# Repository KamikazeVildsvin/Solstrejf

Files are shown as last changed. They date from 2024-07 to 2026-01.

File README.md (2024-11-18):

# Solstrejf - 4 Voice Sine Wave Drone Oscillator
This repository contains the simulation, schematic ,and PCB files for **Solstrejf**.
Some custom KiCad footprints, 3D models, and symbols are used in this project. 
This is included as a git submodule, which means that if you want to work with the KiCad projects in this repo, it should be cloned with the `--recursive` option like so: 

```
git clone --recursive "https://github.com/KamikazeVildsvin/Solstrejf.git"
```

### Introduction & Overview
Solstrejf, roughly translated from Danish to "sun streak" or "sun touch", is a four-voice analog sine wave drone oscillator. 
I was on a hike in Sweden out near a beautiful forest lake just around the break of dawn. 
The way the sun interacted with nature gave me a real sense of calm and ease. 
At that moment I thought, what if I could create an instrument that would be able to replicate this feeling? 
A sine wave drone synthesizer came to my mind, similar to the early Musique Concrète test equipment techniques.

###### Block Diagram
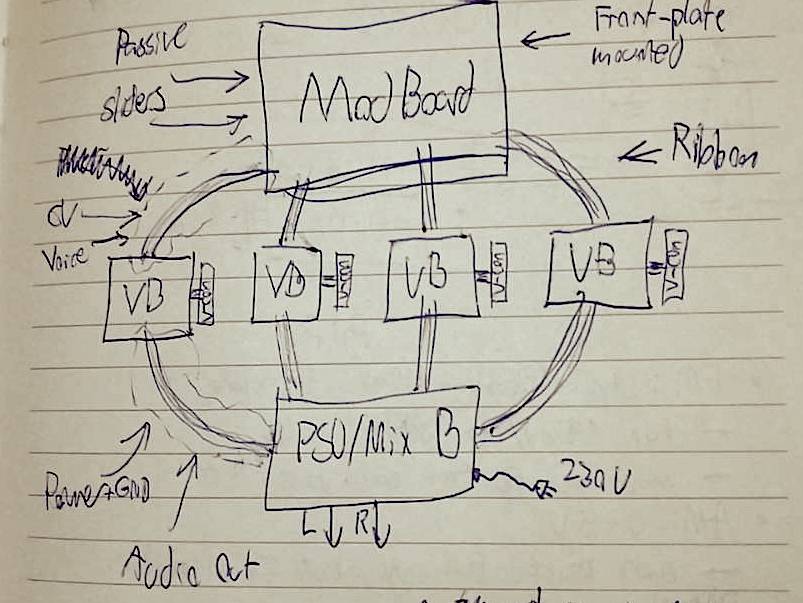
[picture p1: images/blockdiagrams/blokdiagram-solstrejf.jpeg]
Solstrejf Block Diagram


I wanted the instrument to be playful and interactive. 
Four sine wave oscillators in itself are maybe not that interesting and can become static. 
A modulation matrix, which would allow for all four voices to modulate parameters like frequency and amplitude on all other voices would create more complex soundscapes. 
The basic idea and block diagram can be seen above, where four identical voice boards are connected to the mod-matrix board and a power supply/mixer board for output summation.

###### Modulation Matrix & Voice Control Interface
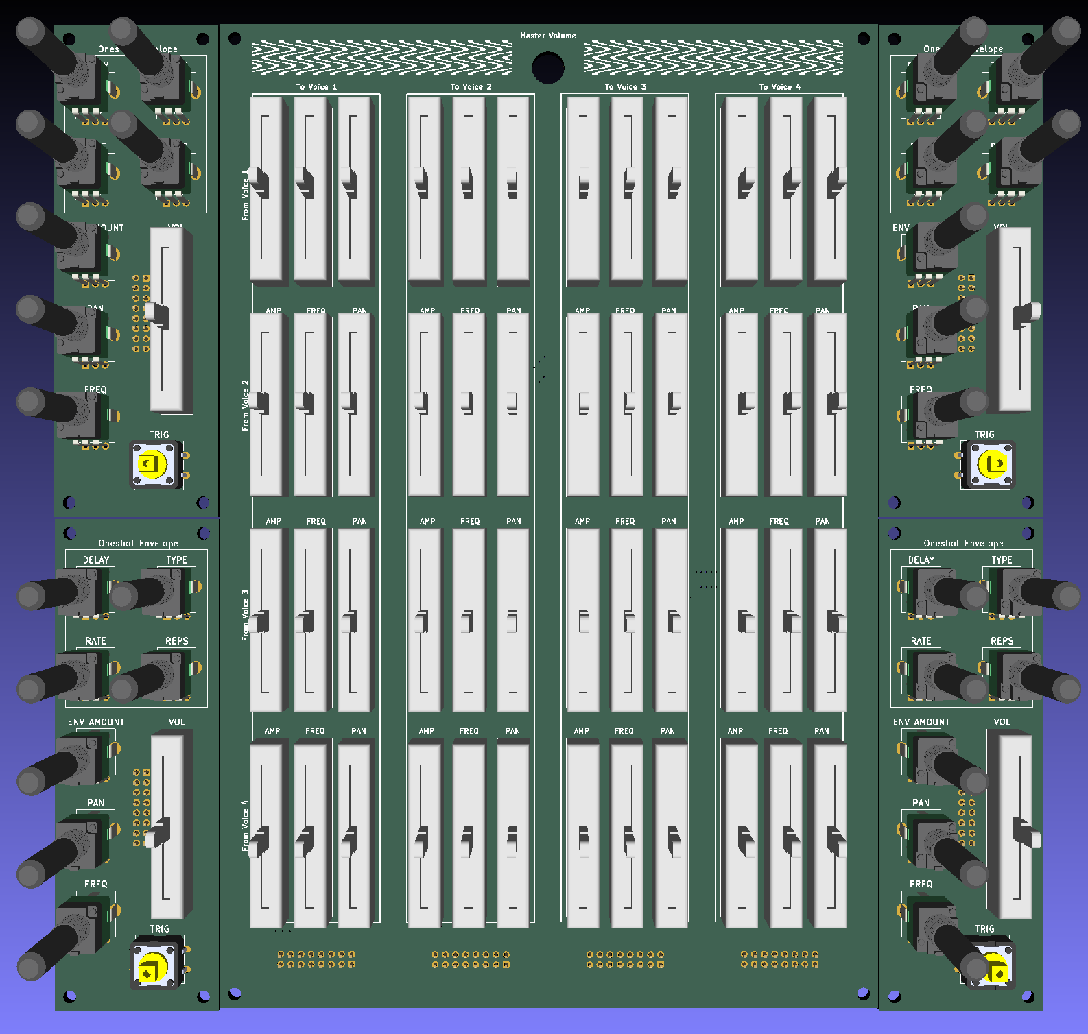
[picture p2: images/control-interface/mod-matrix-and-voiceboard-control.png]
Control Interface


The image above is a render of the modulation matrix and four of the voice board control front panels.
This is essentially user interface of the synthesizer.

## PCB's - KiCad Projects
As indicated by the block diagram above, Solstrejf is broken into four different sub-blocks and PCB's:

- A Power Supply Unit (PSU) & Mixer PCB
- A Modulation Matrix PCB
- A Voice board PCB (x4)
- A Voice board Front Panel PCB (x4)

Each of these PCB's have their own KiCad project with an associated schematic. 
The [`schematics`](schematics) directory contains some of the latest prints of the different schematics. 
The revision may not match with the KiCad files, so be sure to double check the actual KiCad project files to be certain.

#### Interactive BOM
All of the four PCB's have an interactive BOM which is generated using the [InteractiveHtmlBom](https://github.com/openscopeproject/InteractiveHtmlBom) KiCad plugin.
The interactive bom allows to see where the components should be placed on the board and also have a checklist build in, which makes it much easier to assemble the PCB's.
You can also export the BOM to a CSV or TXT file for a more traditional BOM.

### PSU / Audio Mixer
Use to generate the +/-15V supply and sum all of the left and right audio channels of the four voices.

[KiCad Project Files](pcb/solstrejf-PSU-mixer/)

[Link to interactive BOM](https://html-preview.github.io/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)

###### PCB
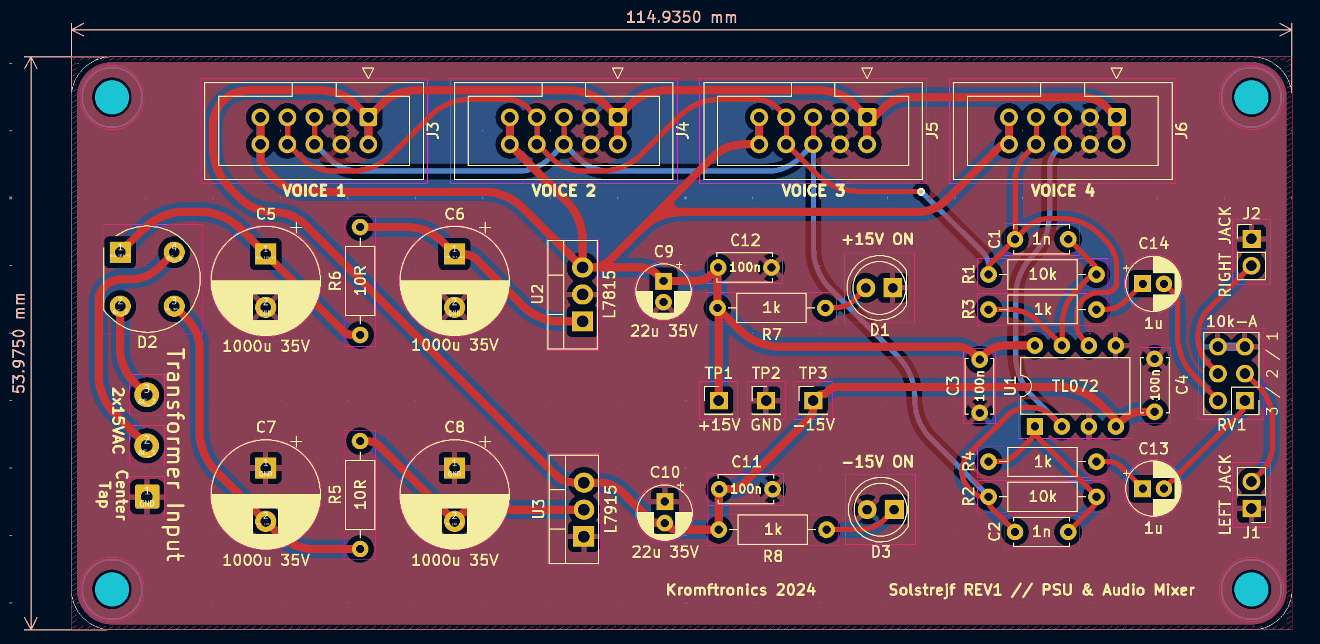
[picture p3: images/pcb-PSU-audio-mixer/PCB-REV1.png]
PSU/audio-mixer PCB


###### 3D Model : Top View
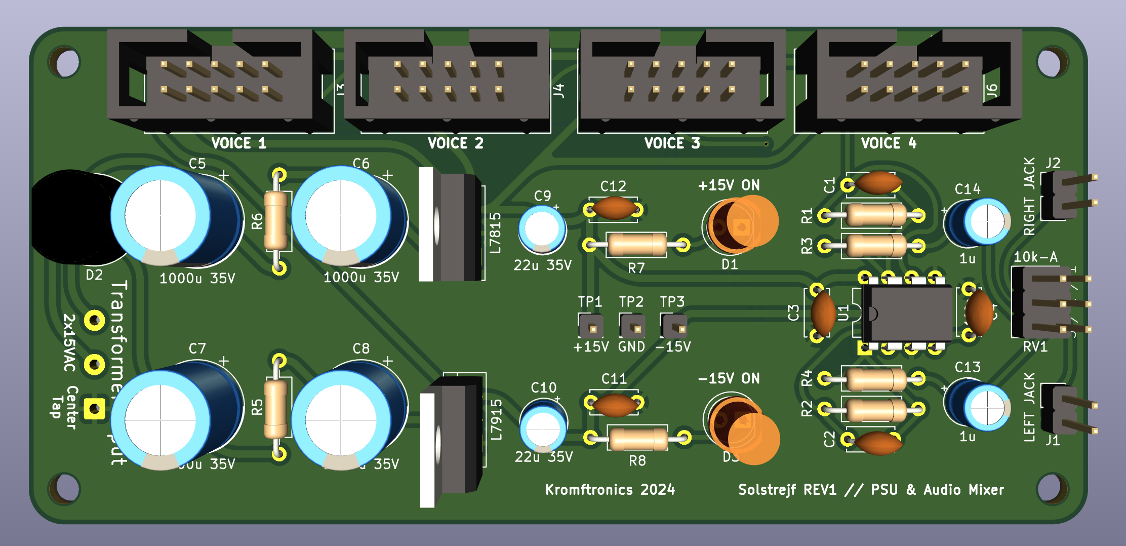
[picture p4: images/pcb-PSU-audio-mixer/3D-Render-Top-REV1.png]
PSU/audio-mixer Top


###### 3D Model : Side View
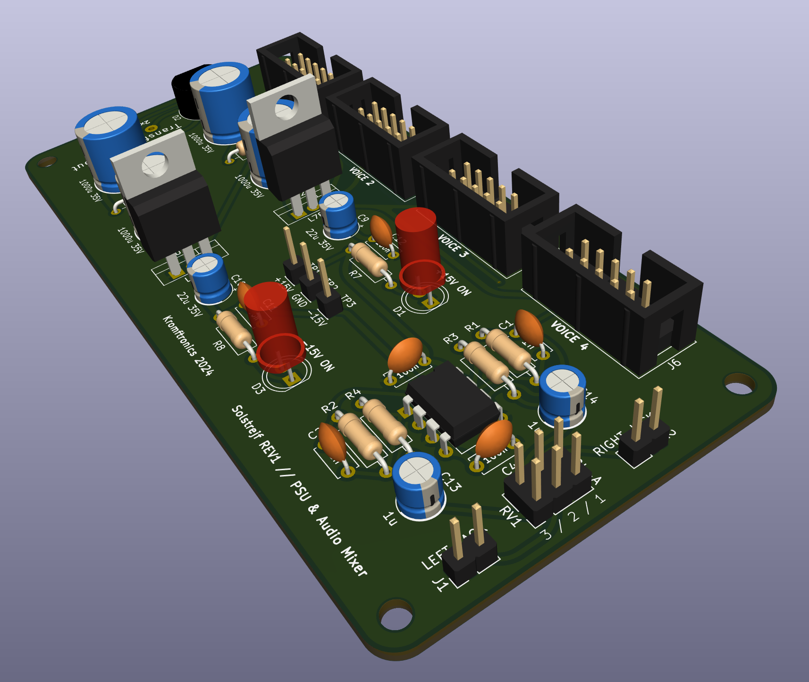
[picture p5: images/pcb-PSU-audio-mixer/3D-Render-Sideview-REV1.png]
PSU/audio-mixer Side


### Mod-Matrix
Connects to each of the four voice boards to route the modulation from and to each of the voices.
Each voice can modulate the amplitude, frequency and pan of all other voices.

[KiCad Project Files](pcb/solstrejf-modmatrix-pots)

[Link to interactive BOM](https://html-preview.github.io/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)

###### PCB 
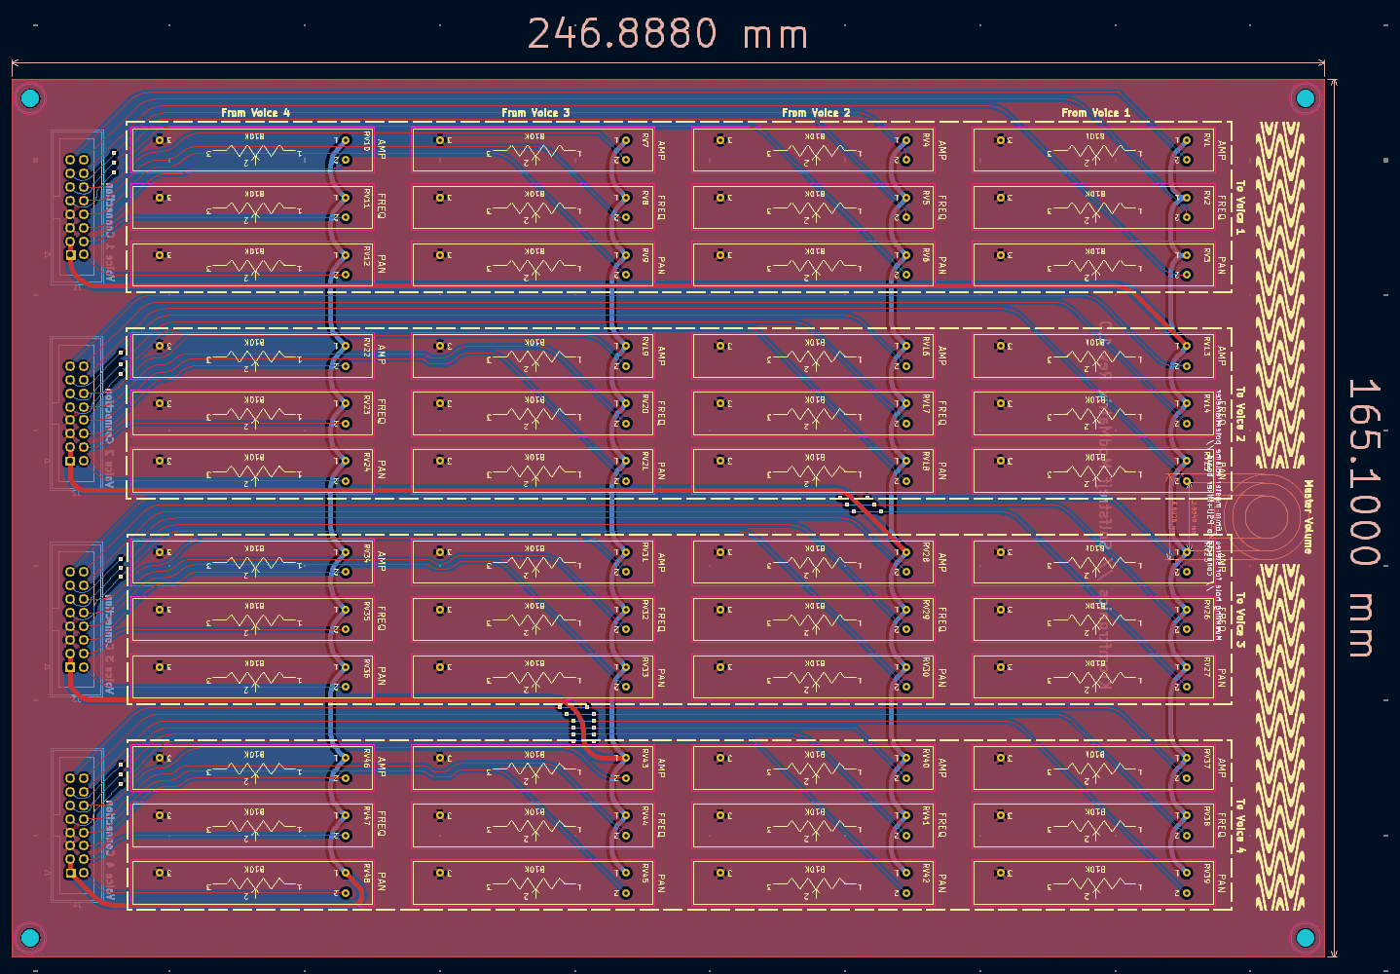
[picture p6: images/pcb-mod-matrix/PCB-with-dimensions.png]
Mod-Matrix PCB


###### 3D Model : Front-Side
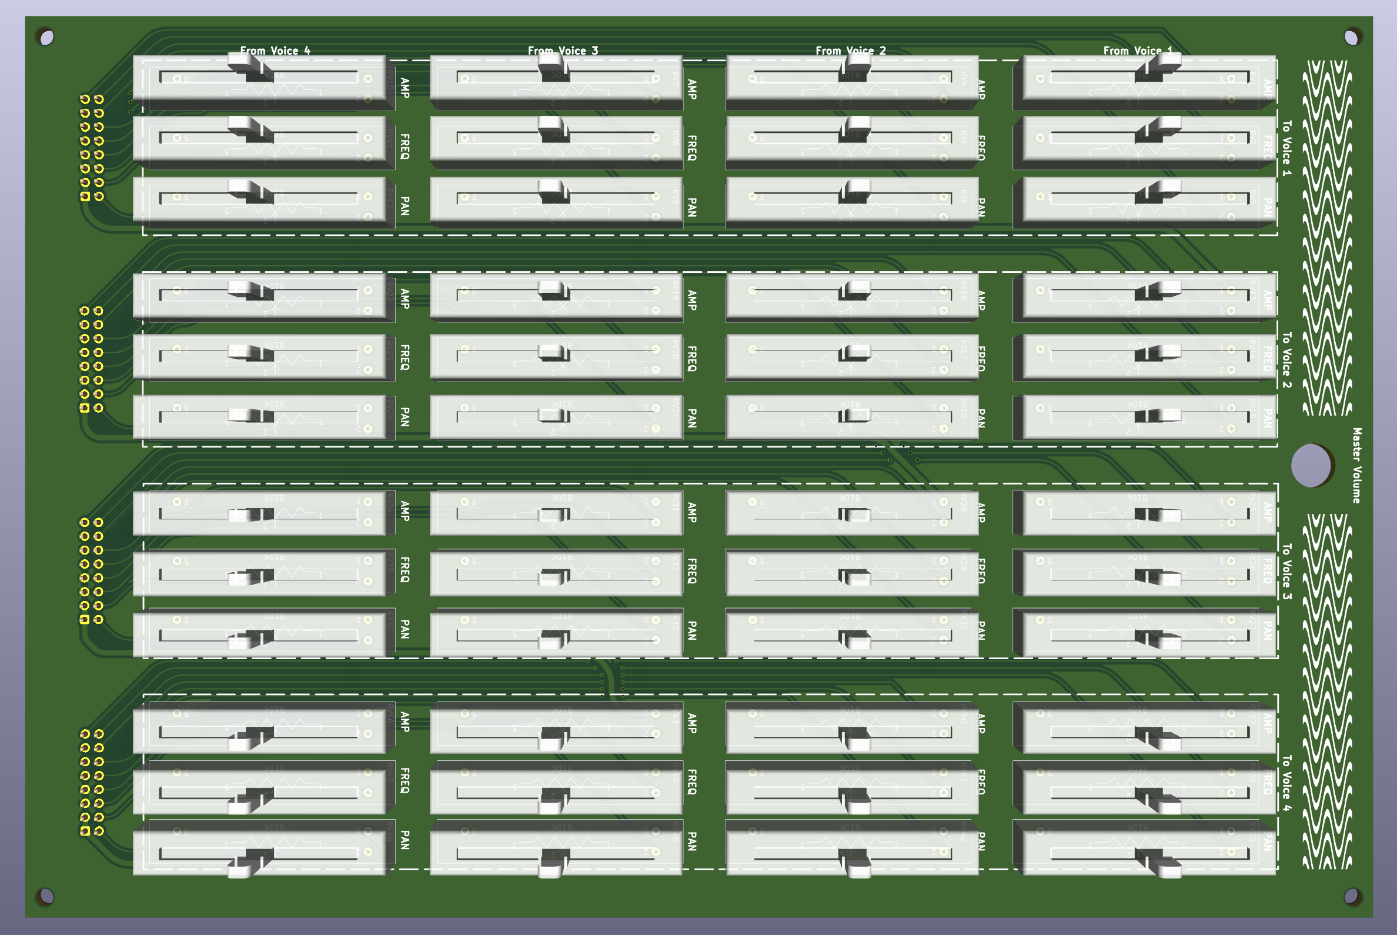
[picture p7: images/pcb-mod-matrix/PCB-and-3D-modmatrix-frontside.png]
Mod-Matrix PCB Front


###### 3D Model : Back-Side 
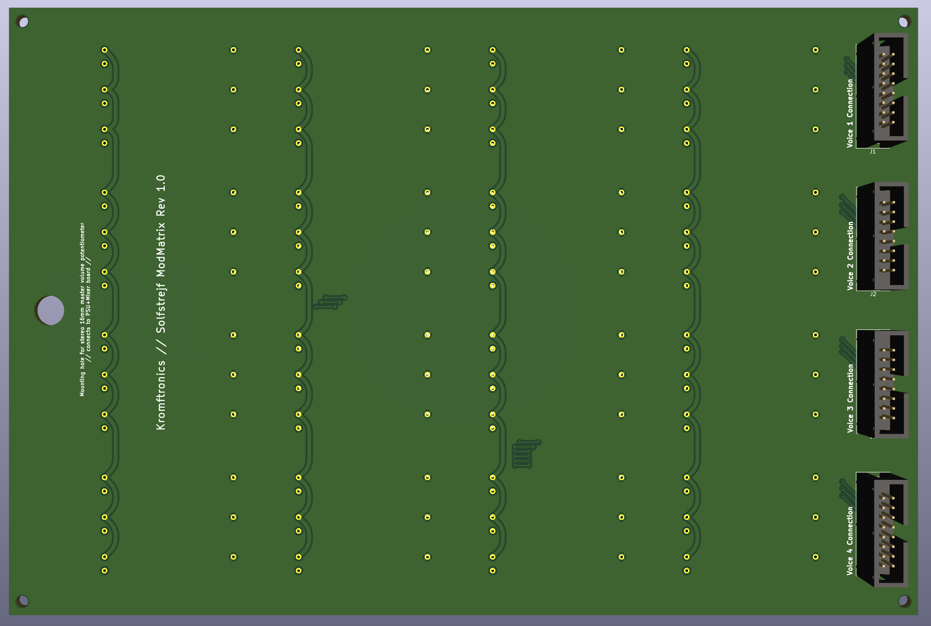
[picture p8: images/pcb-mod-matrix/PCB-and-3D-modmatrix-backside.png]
Mod-Matrix PCB Back


### Voice board 
The voice board is the actual sine wave oscillator and control voltage board.
Solstrejf consists of four of these voice boards.

[KiCad Project Files](pcb/solstrejf-voiceboard-core/)

[Link to interactive BOM](https://html-preview.github.io/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)

###### PCB
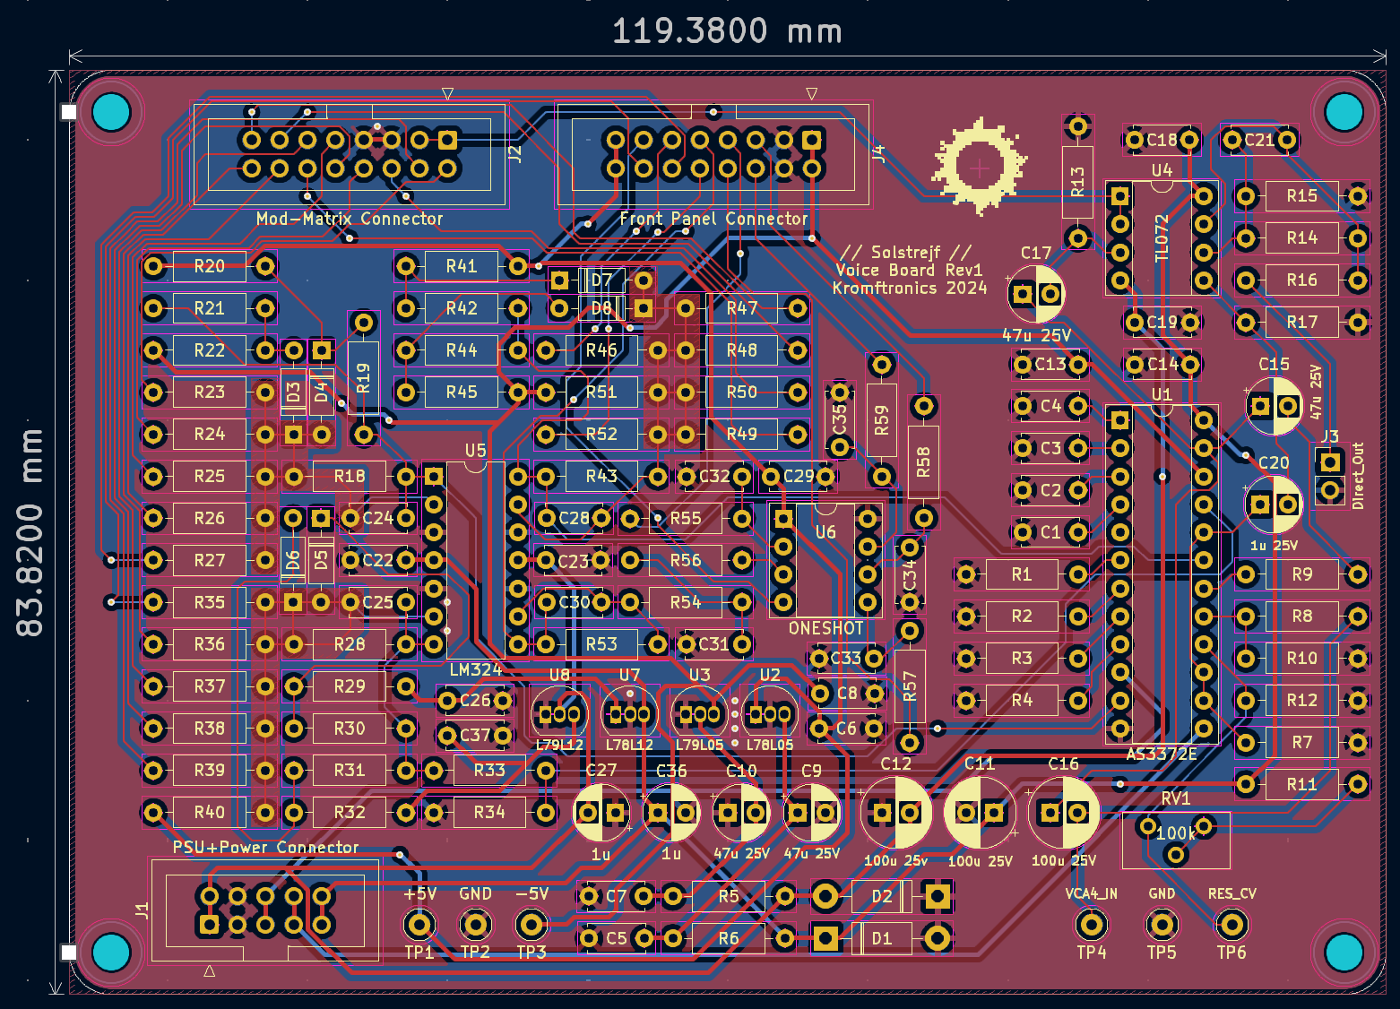
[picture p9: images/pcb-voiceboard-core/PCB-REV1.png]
Voice Board PCB


###### 3D Model : Top View
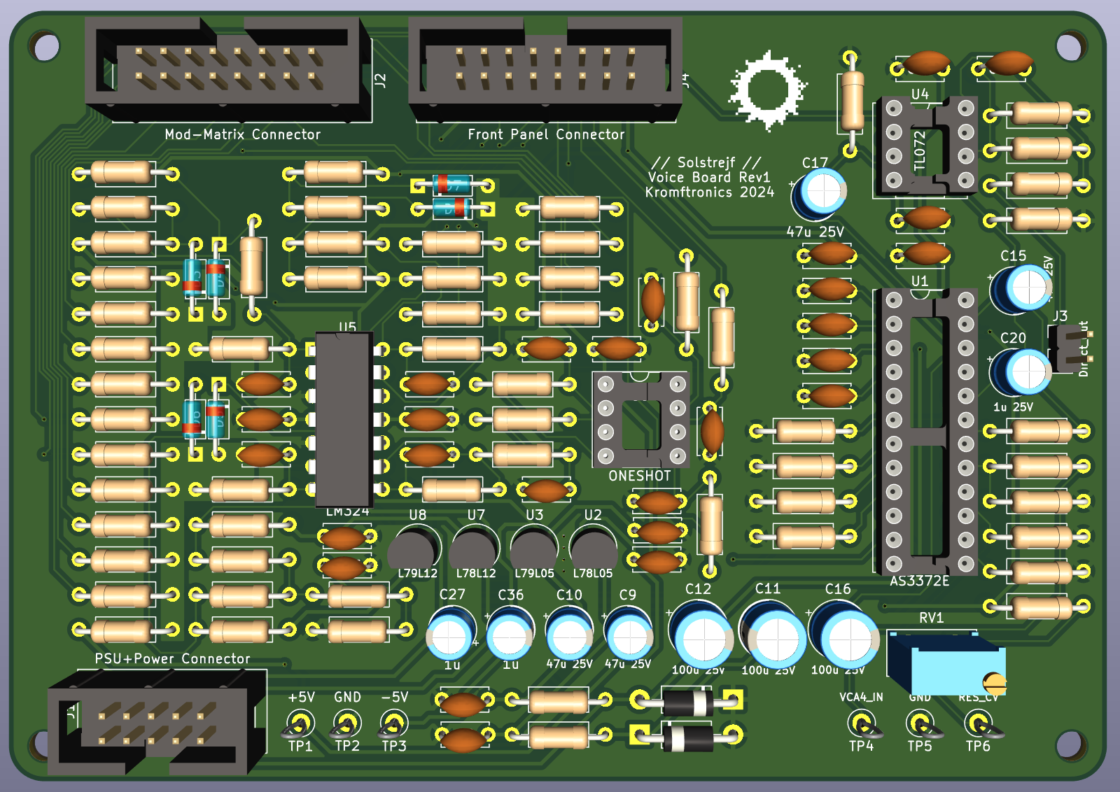
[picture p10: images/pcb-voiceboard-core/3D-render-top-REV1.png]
Voice Board 3D Render Top View


###### 3D Model : Side View
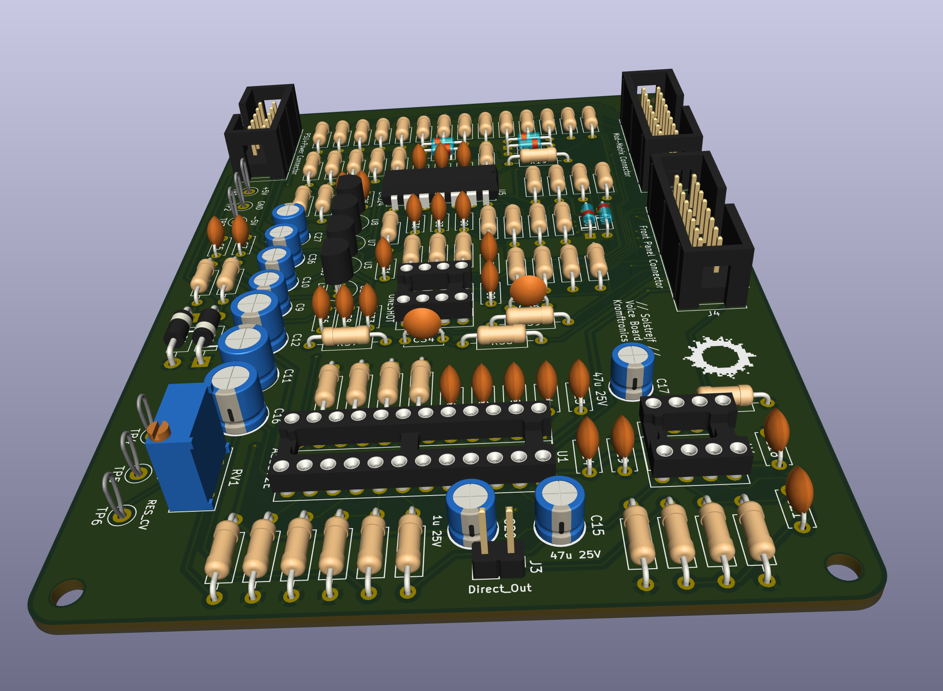
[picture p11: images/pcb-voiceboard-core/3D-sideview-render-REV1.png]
Voice Board 3D Render Top View


### Voice board Front Panel
The voice board needs a control interface for the base pan, frequency, and volume. All of the potentiometers that control the voice board are located on this front panel for easier assembling. 

[KiCad Project Files](pcb/solstrejf-voiceboard-frontpanel/)

[Link to interactive BOM](https://html-preview.github.io/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)

###### PCB 
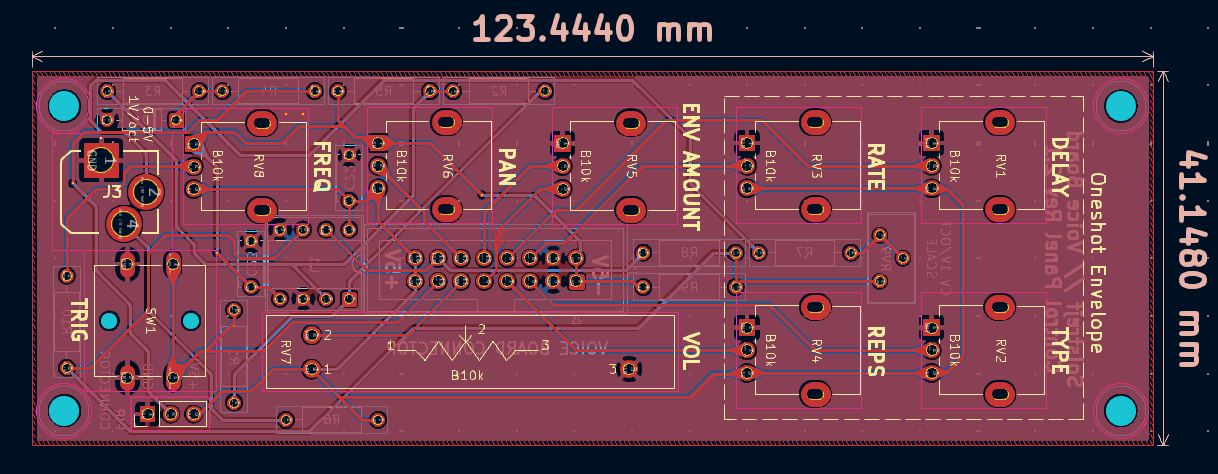
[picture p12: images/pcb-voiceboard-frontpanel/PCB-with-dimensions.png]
Voice Board Control Panel PCB


###### 3D Model : Front Side
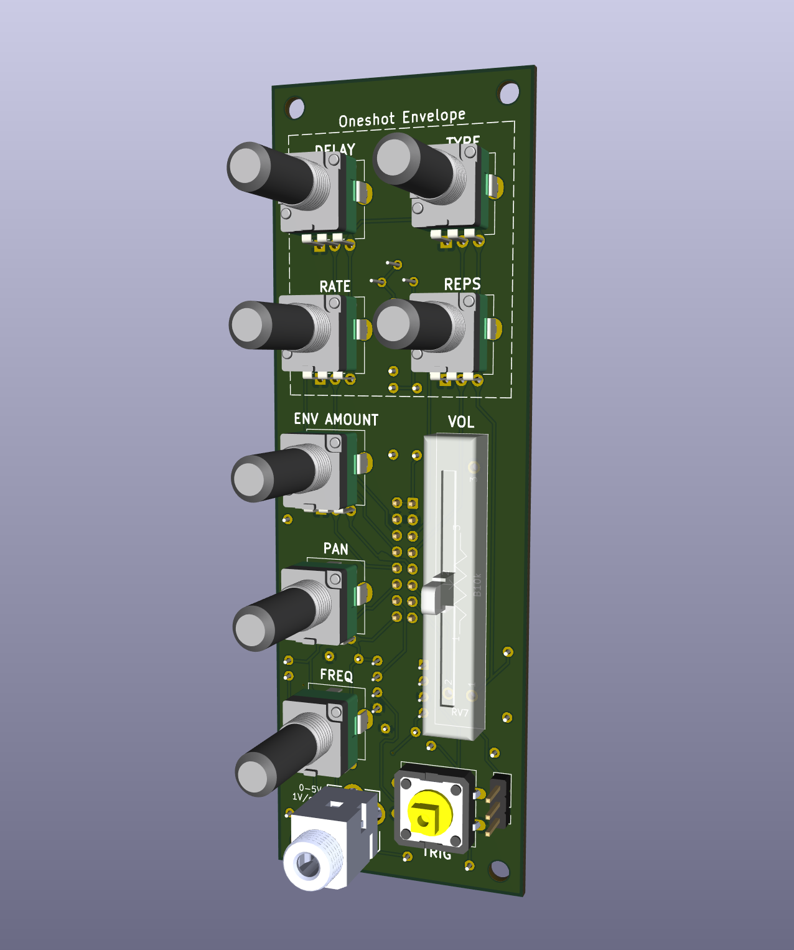
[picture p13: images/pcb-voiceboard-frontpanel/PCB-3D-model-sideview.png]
Voice Board Control Panel PCB Front


###### 3D Model : Back Side 
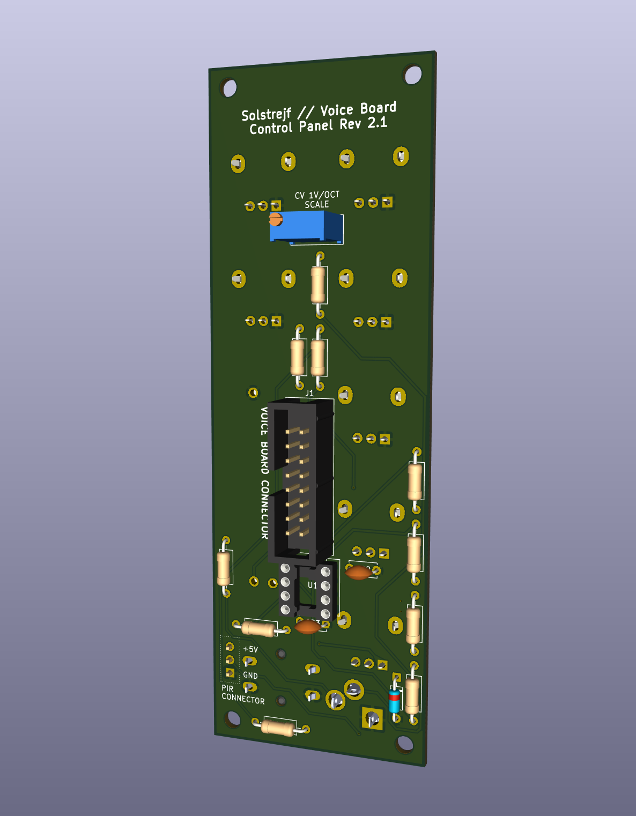
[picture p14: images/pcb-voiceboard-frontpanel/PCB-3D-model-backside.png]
Voice Board Control Panel PCB Back


# Prototype Sponsorship - PCBWay
[PCBway](https://www.pcbway.com/) was so kind to reach out and offer to sponsor the first batch of all four PCBs for Solstrejf!
Essentially, they paid for the production of 5x of each of the four PCBs, which was a great help to reduce the cost of this project.

It was very easy to order from PCBWay using the [PCBWay KiCad Export Plugin](https://github.com/pcbway/PCBWay-Plug-in-for-Kicad).
With one click, all of the needed Gerber and drill files were created and packaged in a neat zip file that could be uploaded directly to PCBWay's website for ordering.

I'm very satisfied with the build quality of the PCBs that I have received for my first prototype of Solstrejf.
The silkscreen and edge cuts were very smooth and pleasant to look at, which especially is nice for the modulation matrix and the voice board front panels (since the user has to look at these PCBs).

Thanks to PCBWay for sponsoring the prototype PCBs.

*pictures coming soon...*

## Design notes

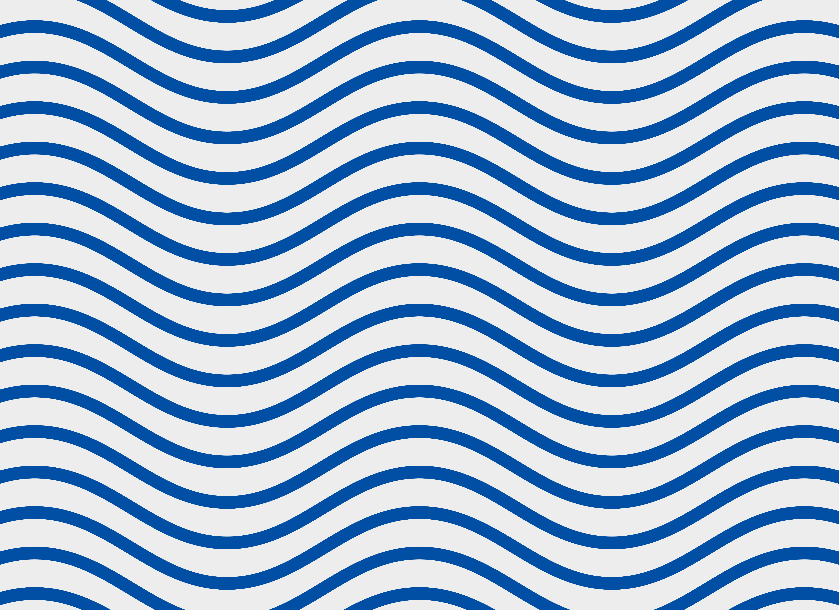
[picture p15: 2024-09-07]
pcb/solstrejf-modmatrix-pots/silkscreen-art/sinewave-art-mod-matrix.jpg

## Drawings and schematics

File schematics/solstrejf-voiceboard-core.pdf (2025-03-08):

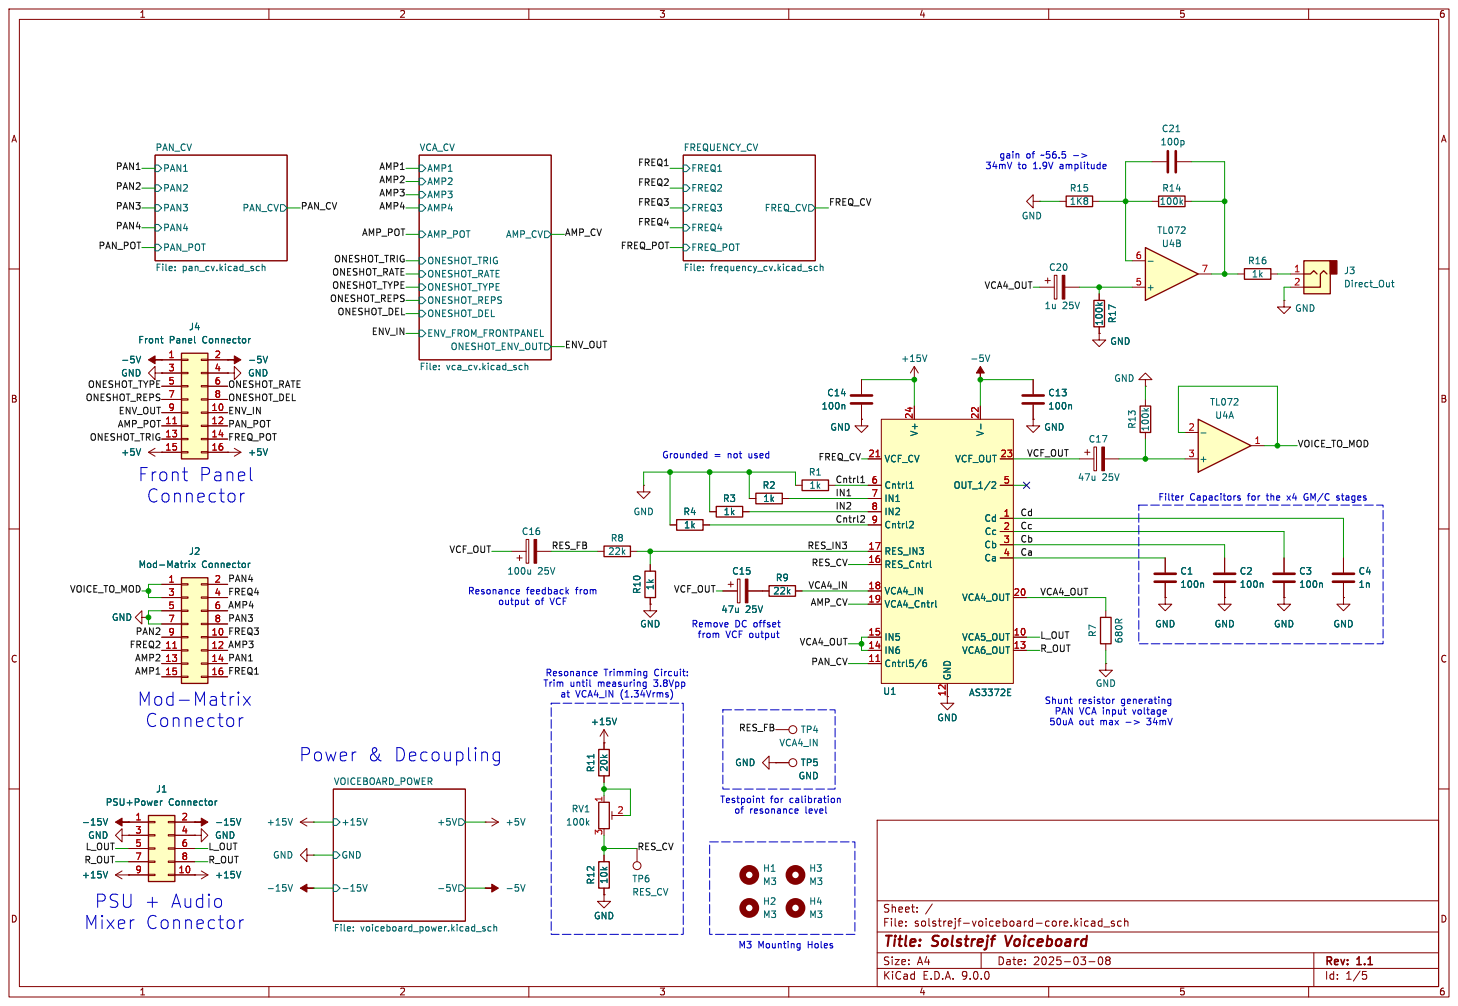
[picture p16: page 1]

File: solstrejf-voiceboard-core.kicad_sch Sheet: /
Id: 1/5 Title: Solstrejf Voiceboard

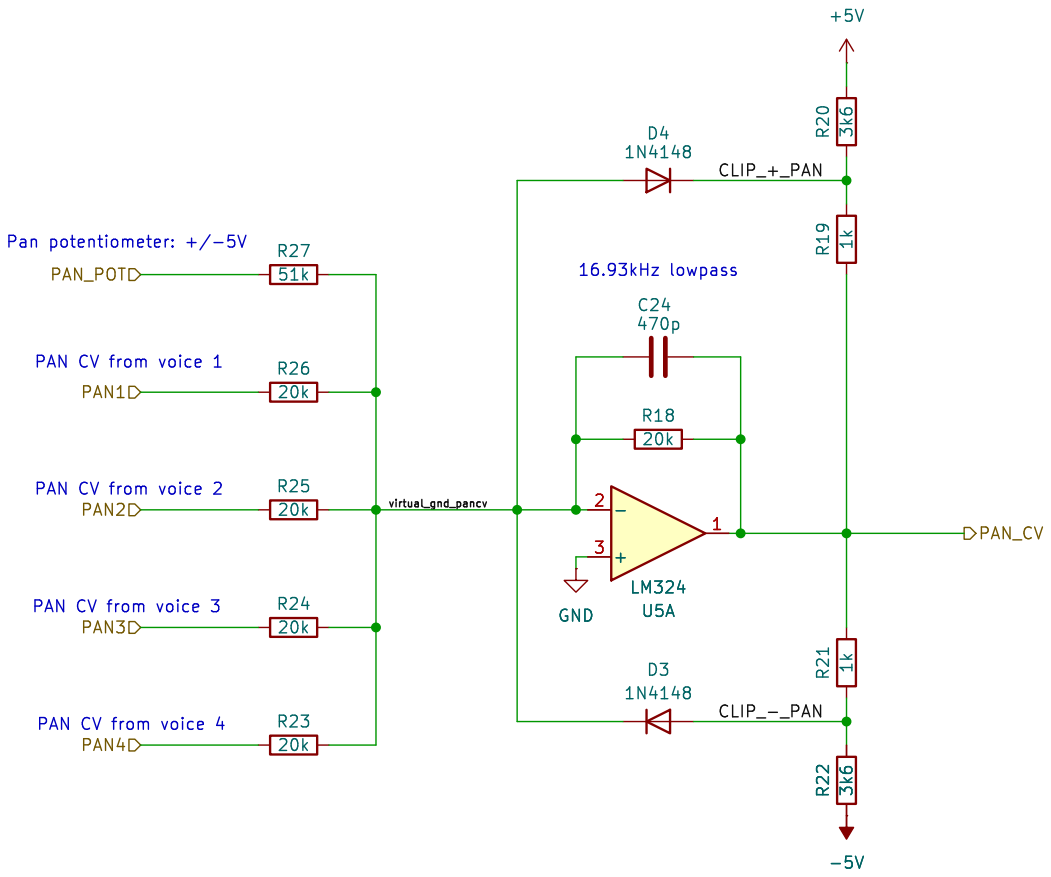
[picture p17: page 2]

PAN CV from voice 1

virtual_gnd_pancv PAN CV from voice 3 PAN CV from voice 4

Id: 2/5 Title: Pan Control Voltage Summing Amplifier File: pan_cv.kicad_sch Sheet: /PAN_CV/ R24

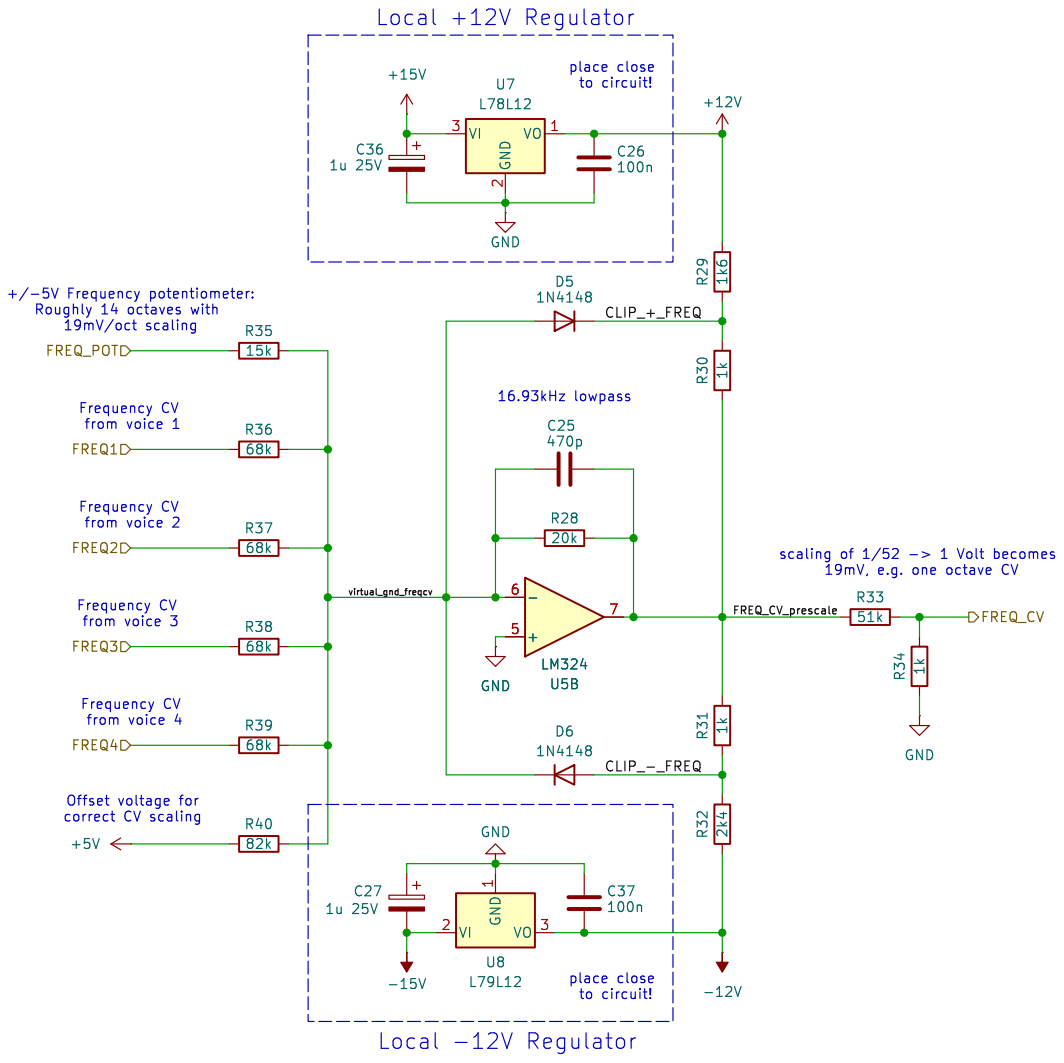
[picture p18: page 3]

to circuit! Frequency CV

Frequency CV
from voice 3 Frequency CV

Id: 3/5 Title: Frequency Control Voltage Summing Amplifier File: frequency_cv.kicad_sch Sheet: /FREQUENCY_CV/

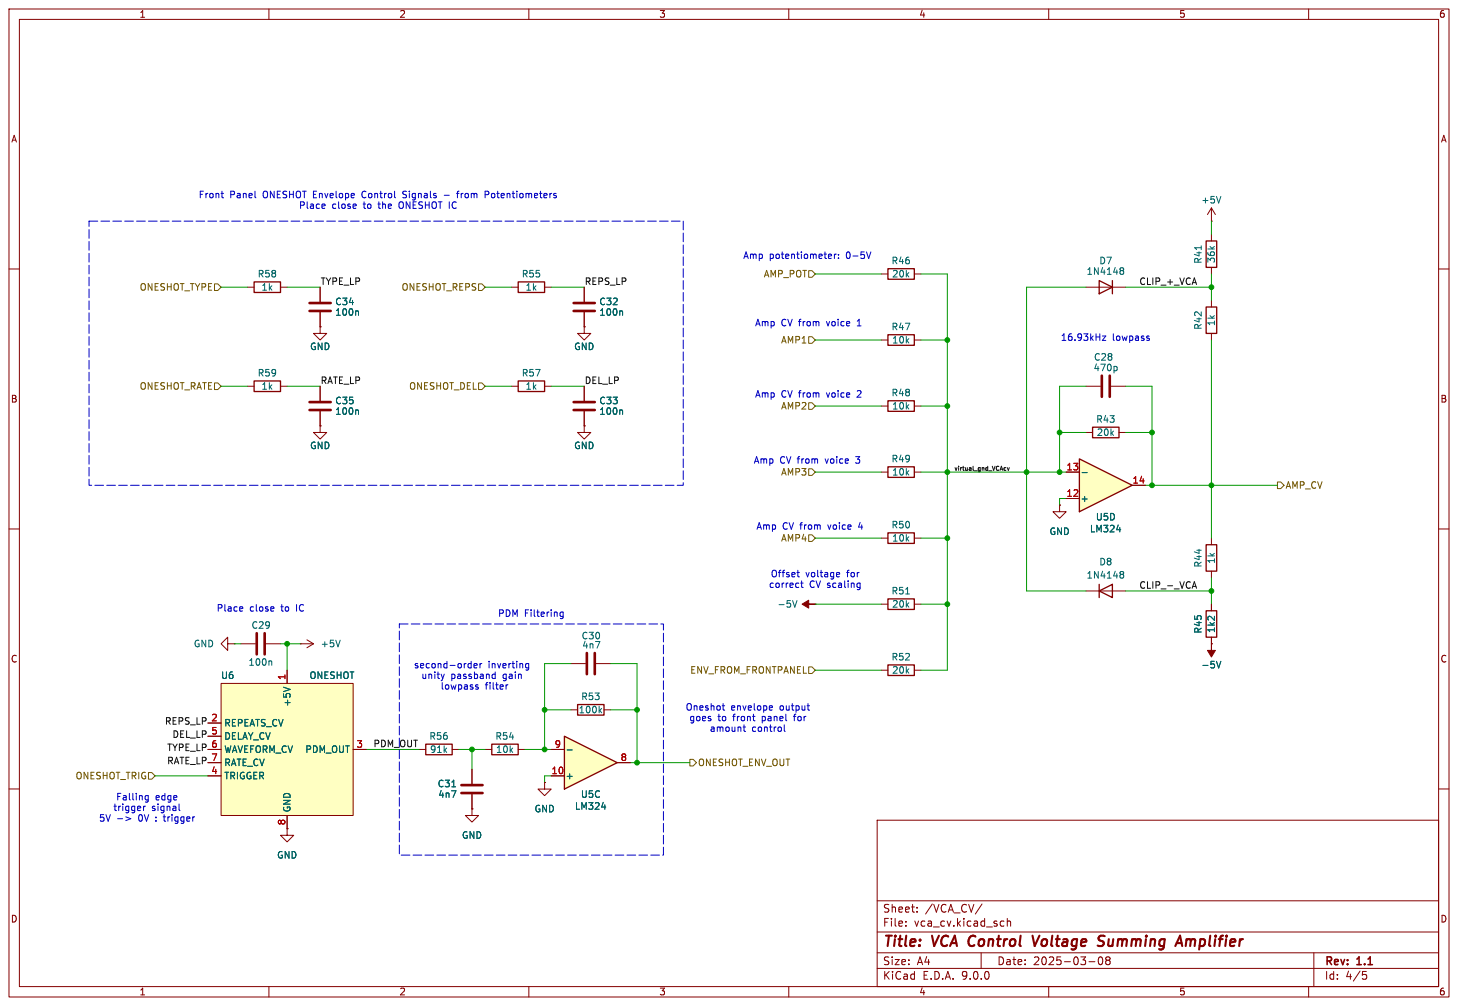
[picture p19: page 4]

Front Panel ONESHOT Envelope Control Signals - from Potentiometers Place close to the ONESHOT IC

Amp CV from voice 2 Amp CV from voice 3 Amp CV from voice 4 GND

Id: 4/5 Title: VCA Control Voltage Summing Amplifier File: vca_cv.kicad_sch Sheet: /VCA_CV/ R51

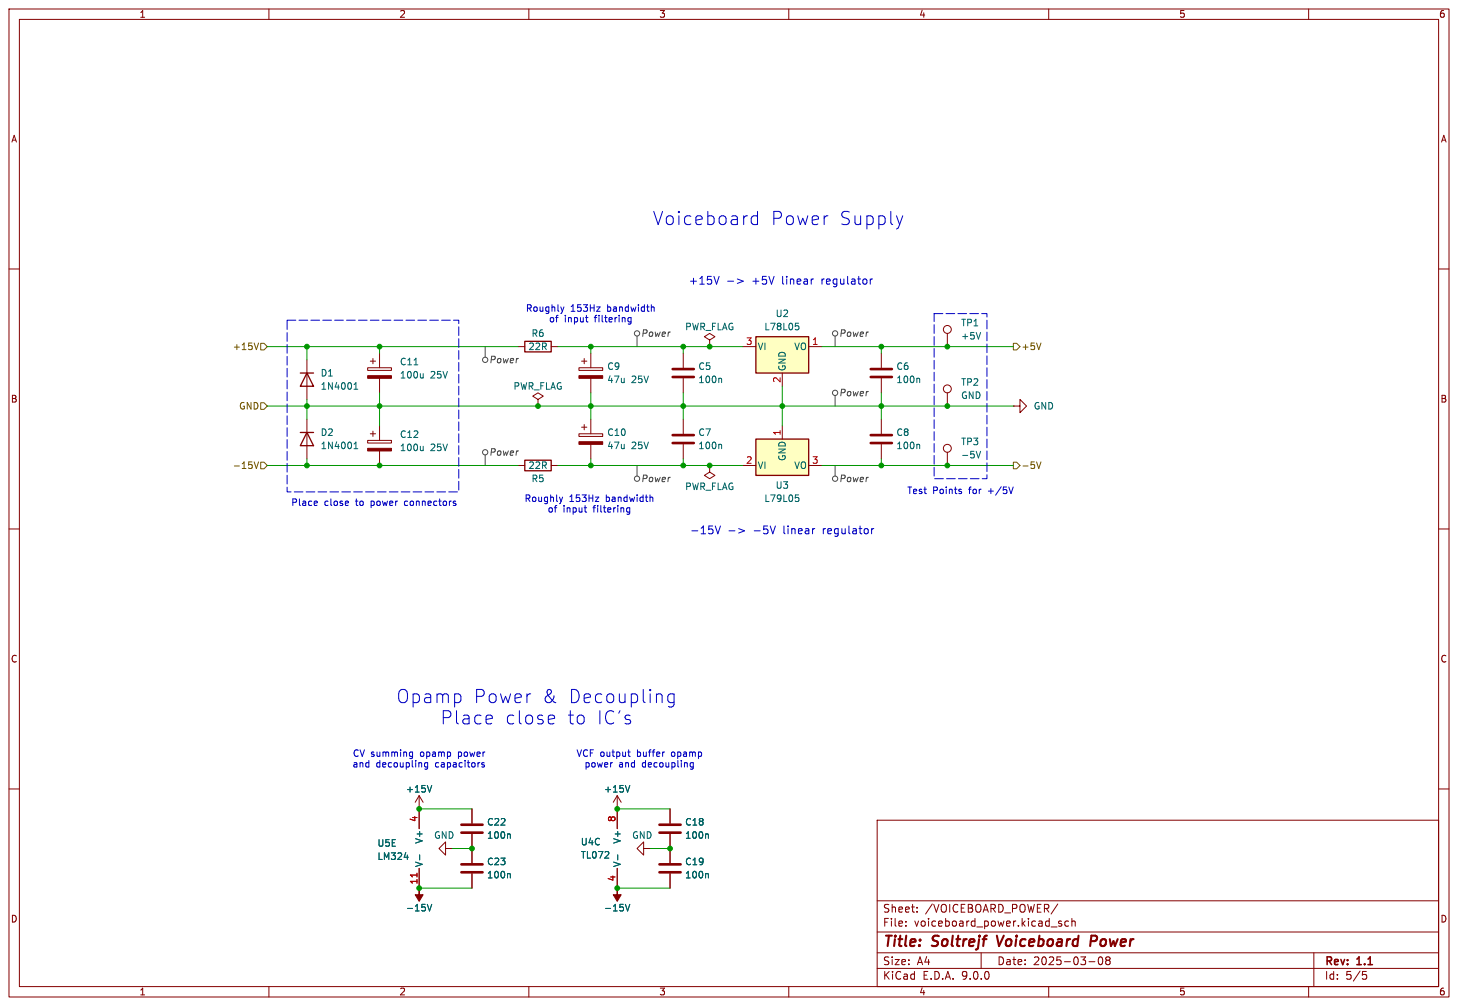
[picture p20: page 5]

Opamp Power & Decoupling
Place close to IC's

VCF output buffer opamp
power and decoupling

Id: 5/5 Title: Soltrejf Voiceboard Power File: voiceboard_power.kicad_sch Sheet: /VOICEBOARD_POWER/

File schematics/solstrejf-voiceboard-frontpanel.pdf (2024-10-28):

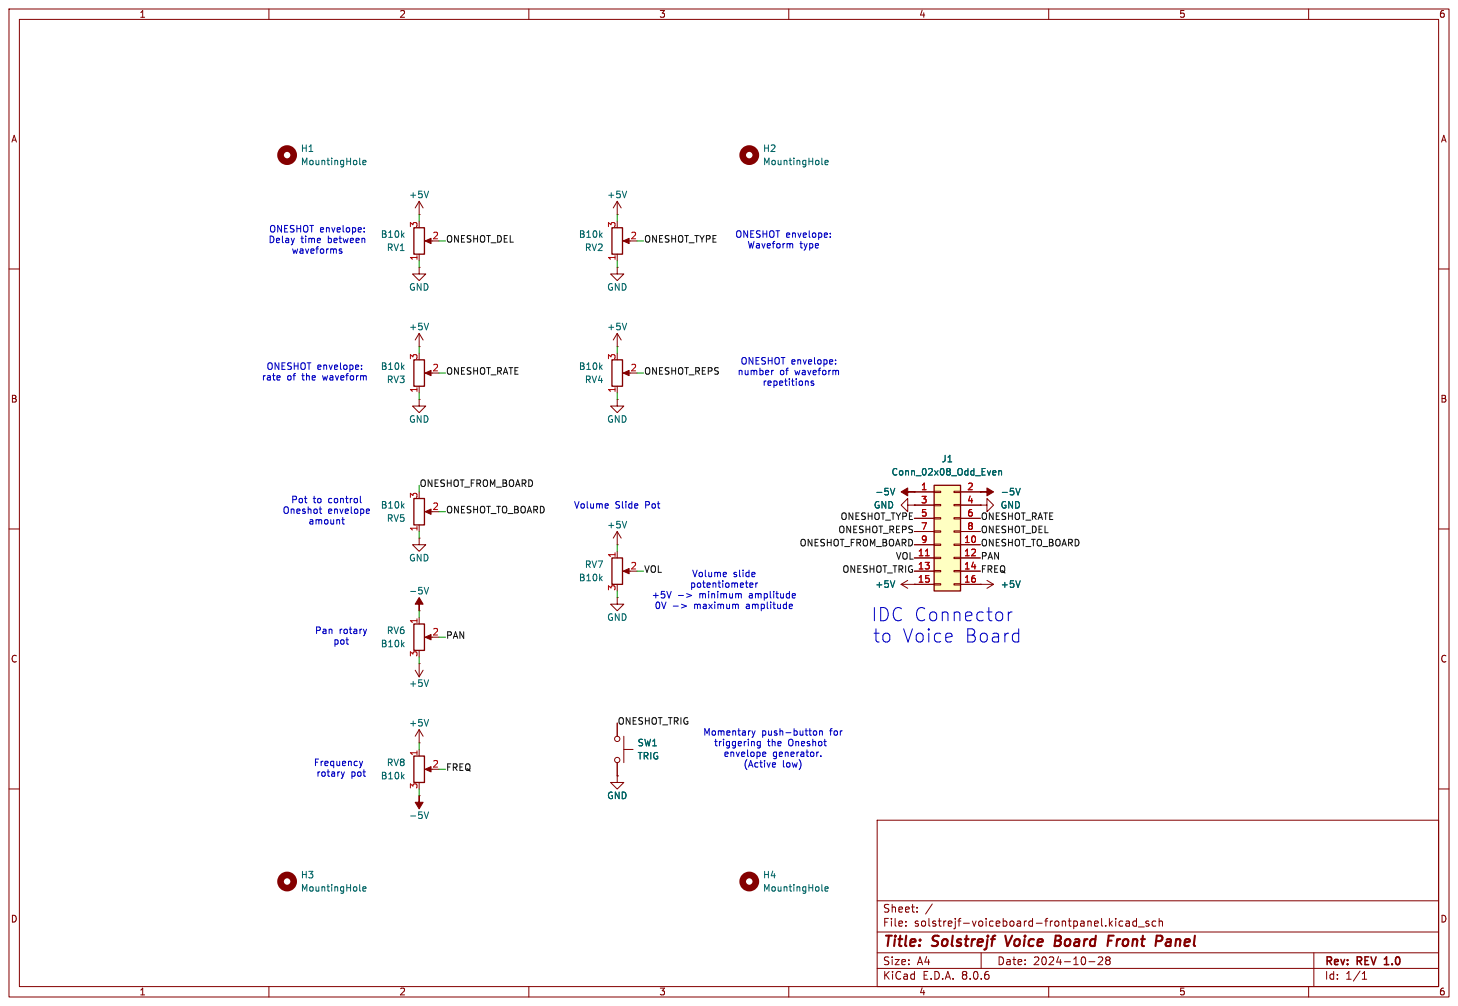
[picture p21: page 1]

repetitions ONESHOT envelope:
Delay time between waveforms

Pot to control Oneshot envelope

Id: 1/1 Title: Solstrejf Voice Board Front Panel File: solstrejf-voiceboard-frontpanel.kicad_sch Sheet: / H3 MountingHole

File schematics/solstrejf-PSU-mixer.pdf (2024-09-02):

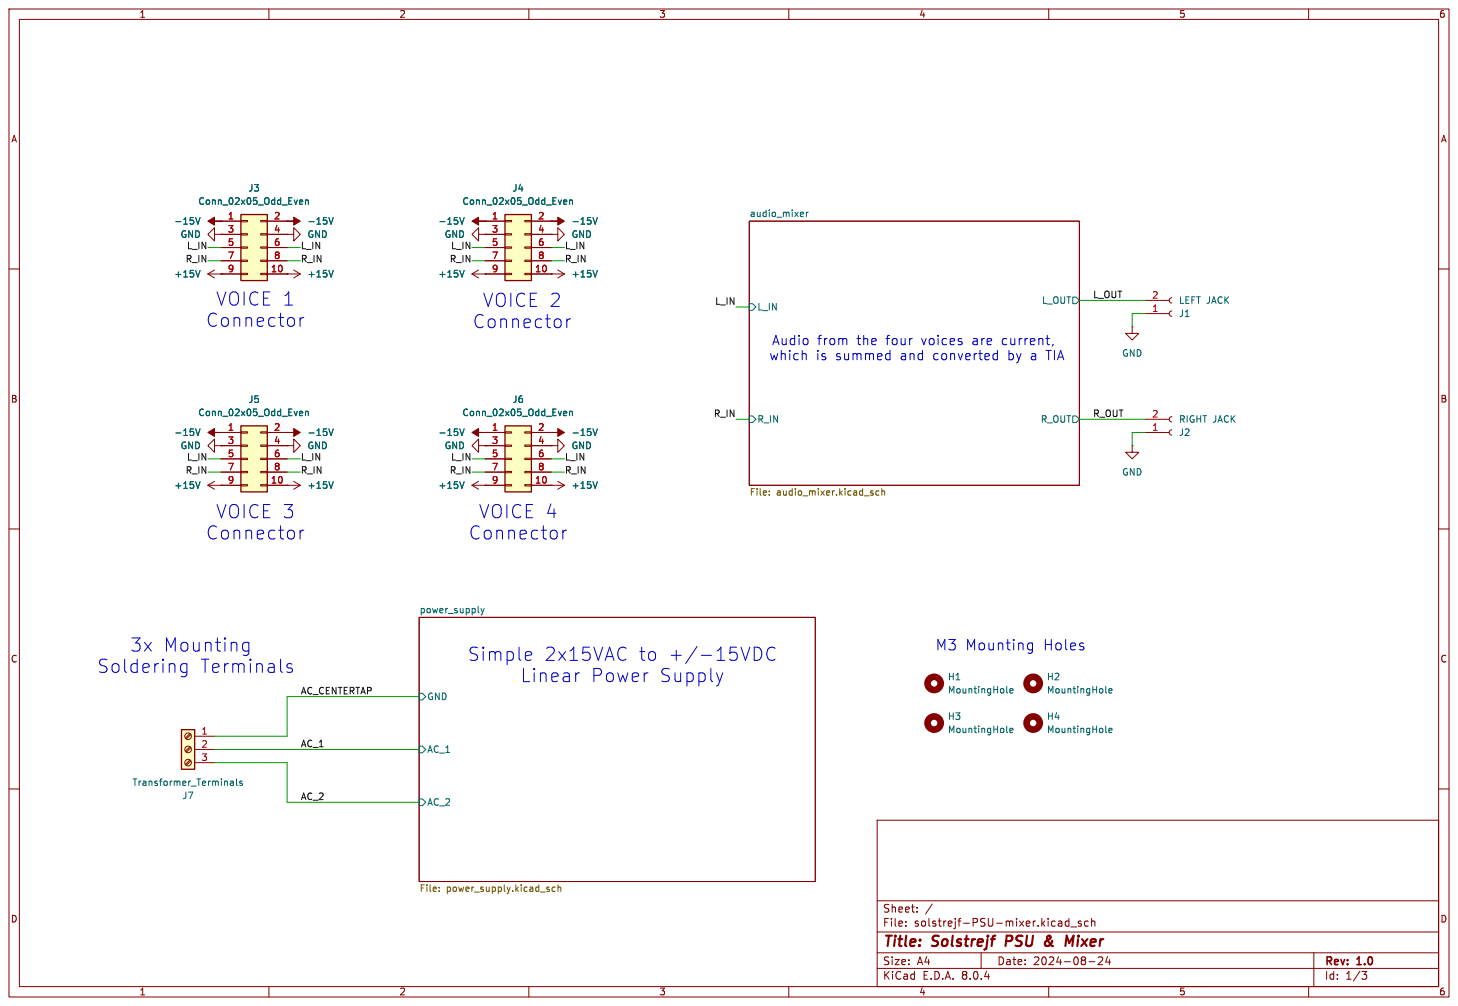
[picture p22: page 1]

Audio from the four voices are current,
which is summed and converted by a TIA

Id: 1/3 Title: Solstrejf PSU & Mixer File: solstrejf-PSU-mixer.kicad_sch Sheet: /

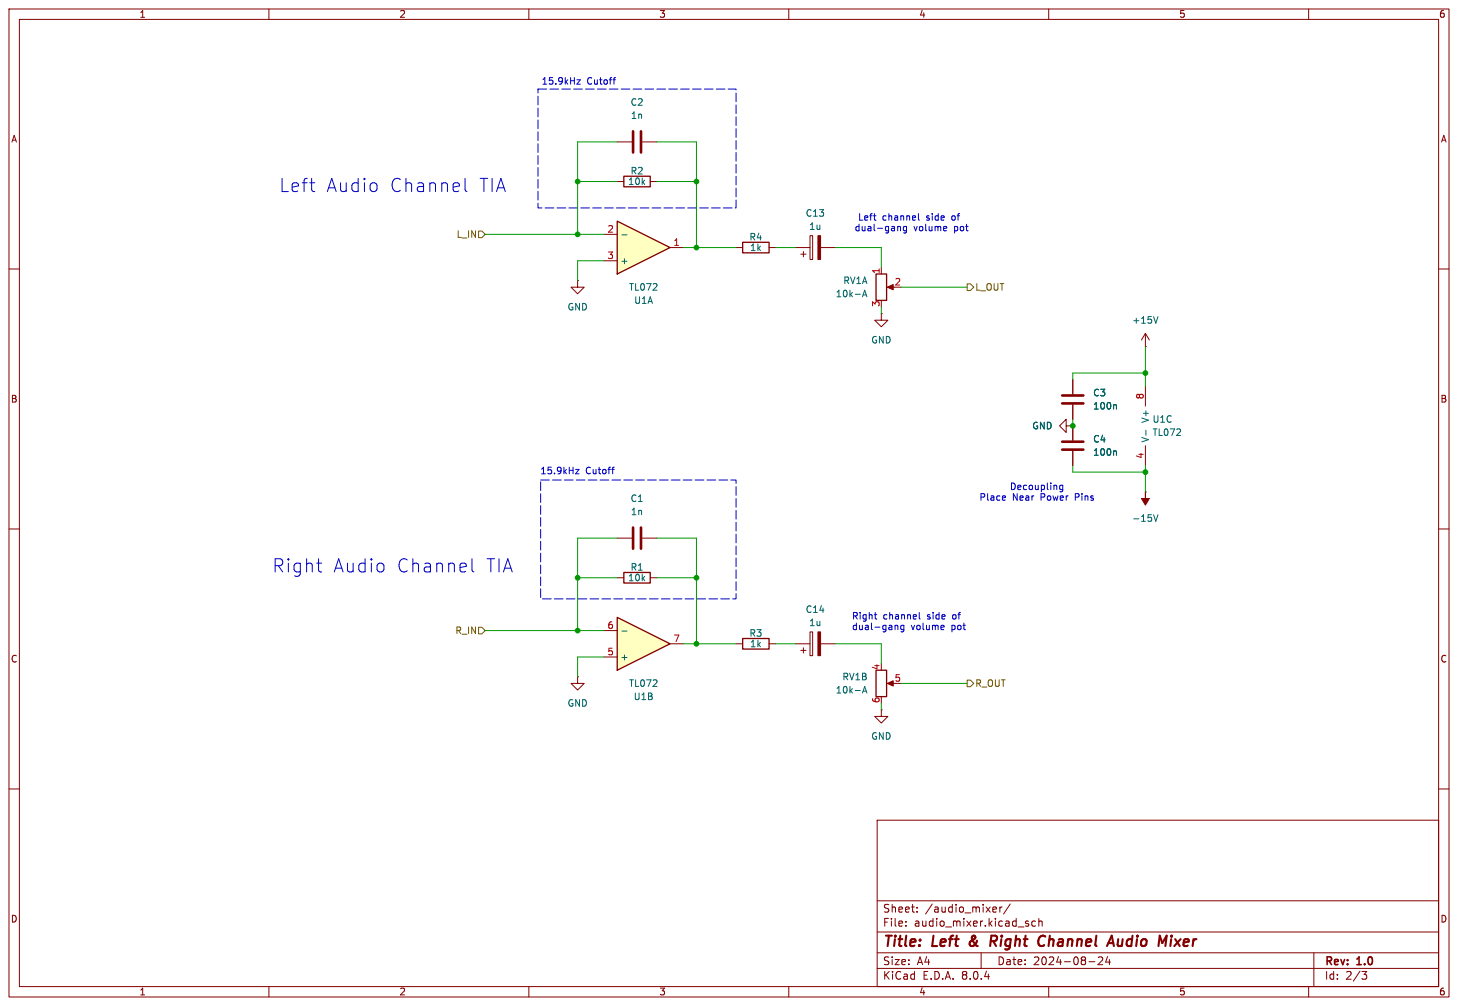
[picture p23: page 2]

Id: 2/3 Title: Left & Right Channel Audio Mixer File: audio_mixer.kicad_sch Sheet: /audio_mixer/

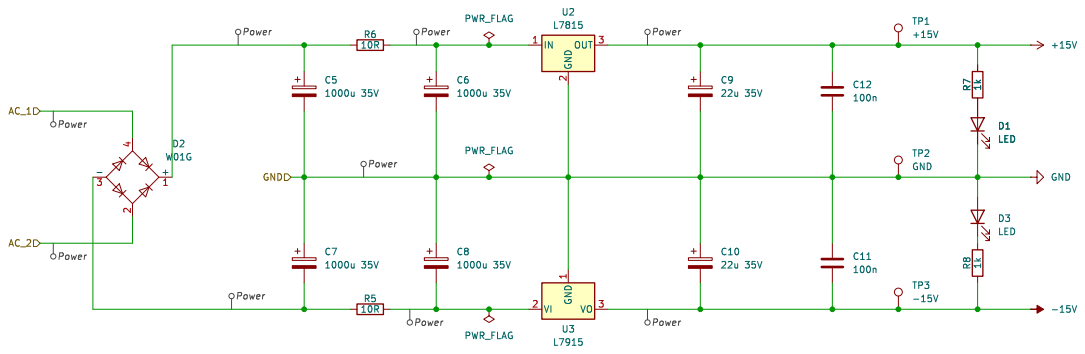
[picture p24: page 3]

Id: 3/3 Title: Linear Split Supply AC-DC Converter File: power_supply.kicad_sch Sheet: /power_supply/

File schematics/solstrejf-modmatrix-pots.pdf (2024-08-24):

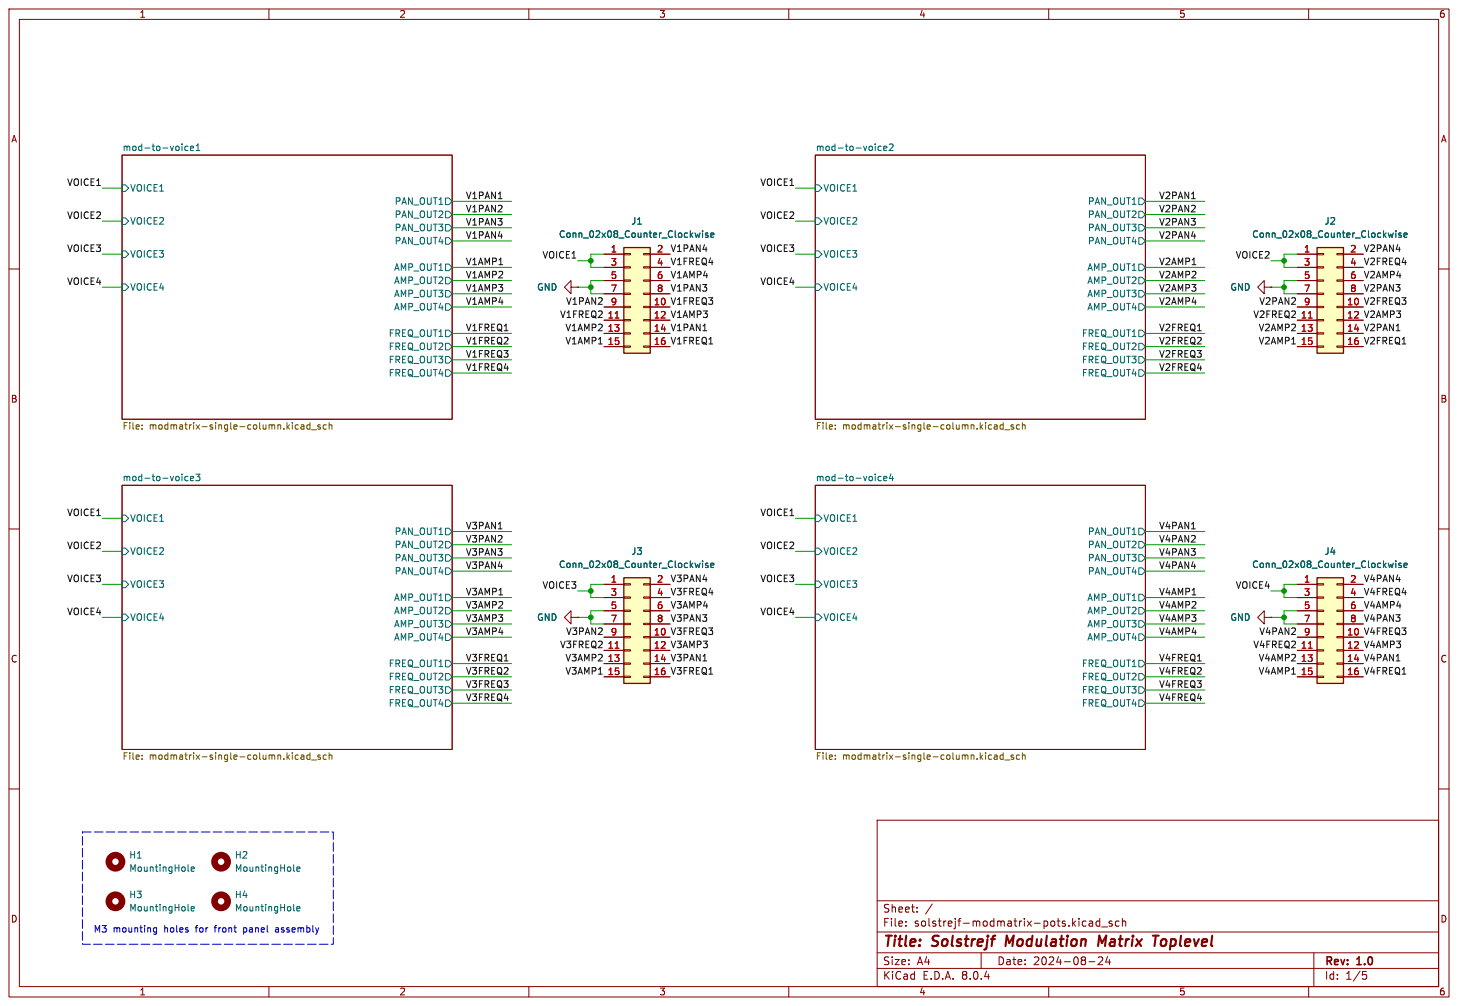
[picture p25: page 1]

Id: 1/5 Title: Solstrejf Modulation Matrix Toplevel File: solstrejf-modmatrix-pots.kicad_sch Sheet: /

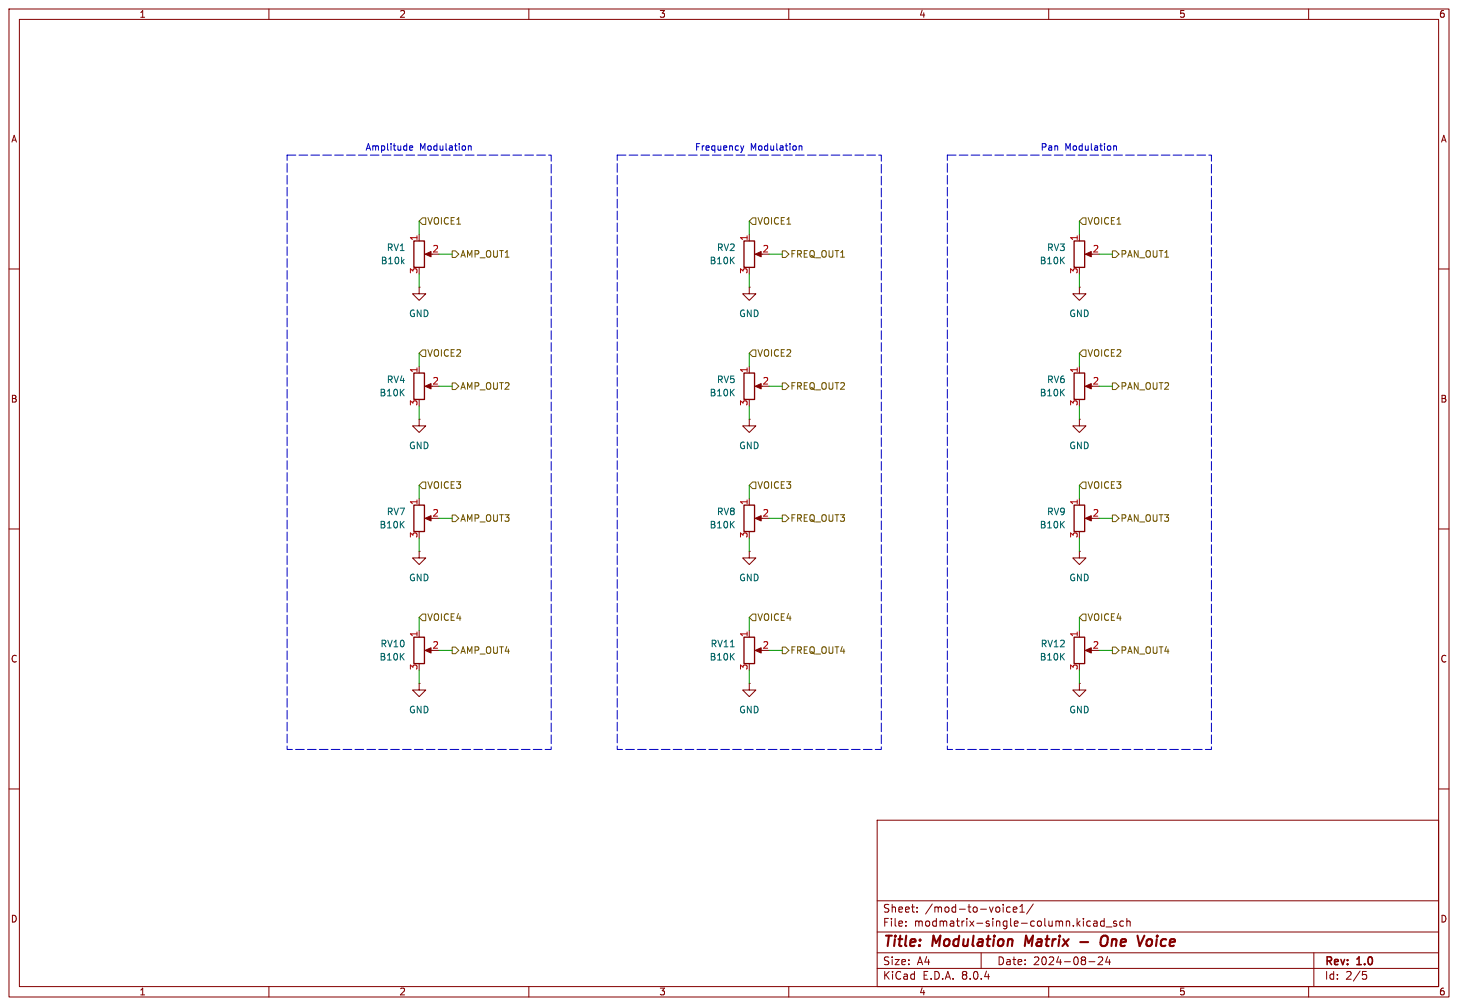
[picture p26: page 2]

3 RV1 B10k FREQ_OUT2 VOICE3 AMP_OUT4 VOICE4 VOICE4 VOICE3 VOICE1 VOICE2FREQ_OUT1 VOICE3PAN_OUT2 FREQ_OUT3 VOICE1 VOICE2PAN_OUT1 FREQ_OUT4 VOICE4 AMP_OUT2 VOICE1 VOICE2AMP_OUT1 PAN_OUT3 PAN_OUT4 AMP_OUT3 Amplitude Modulation Frequency Modulation Pan Modulation

File: modmatrix-single-column.kicad_sch Sheet: /mod-to-voice1/
Id: 2/5 Title: Modulation Matrix - One Voice

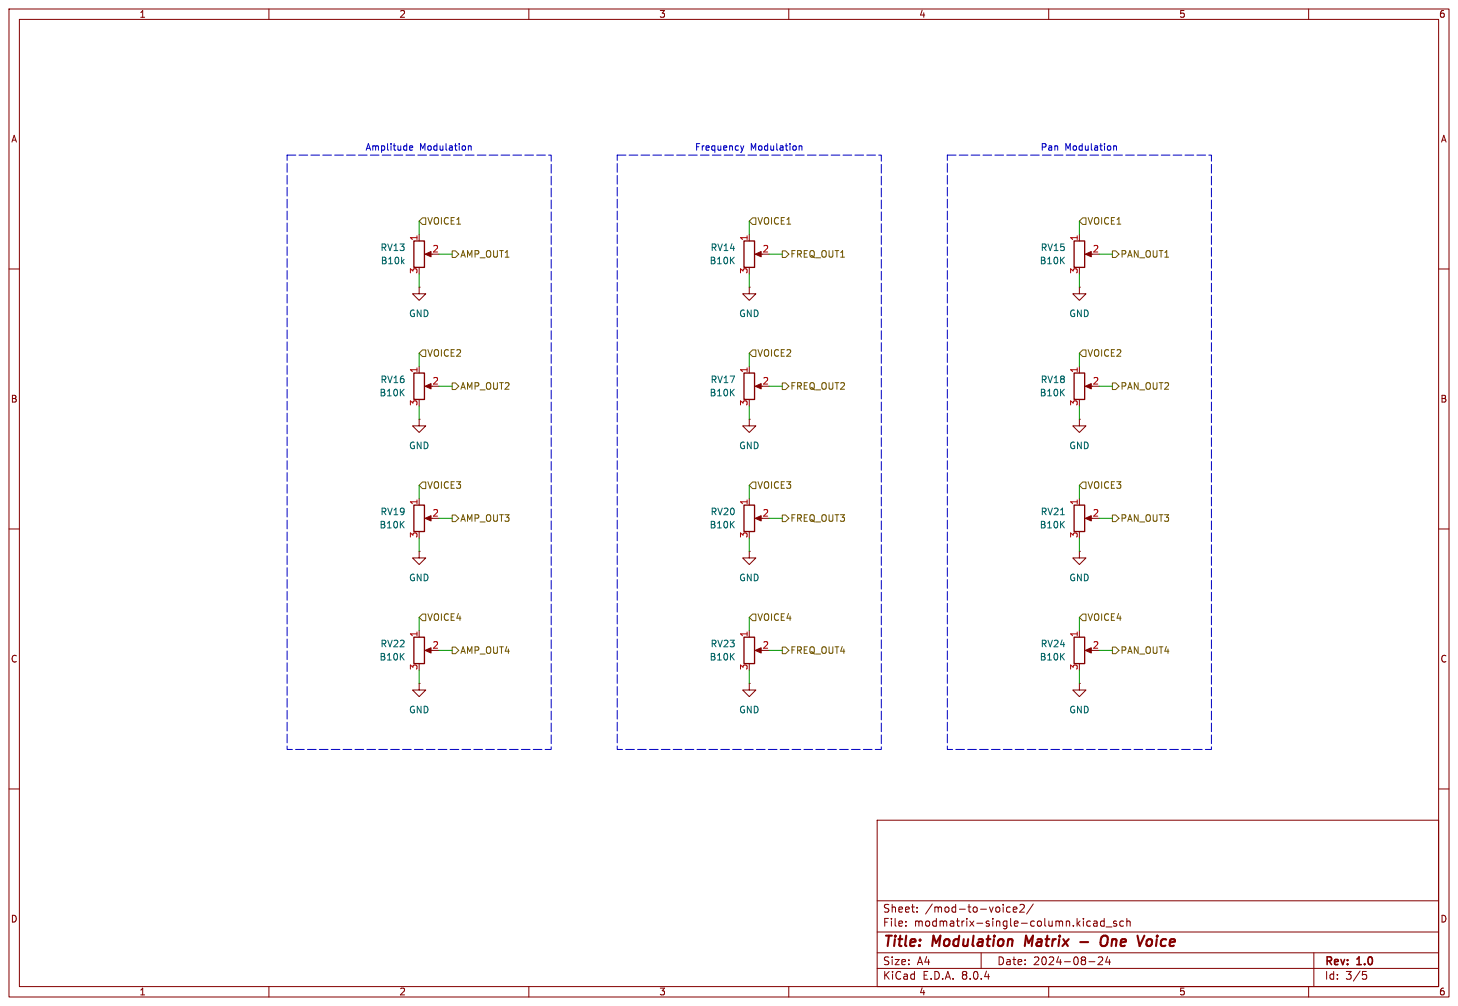
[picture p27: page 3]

Id: 3/5 Title: Modulation Matrix - One Voice


File: modmatrix-single-column.kicad_sch Sheet: /mod-to-voice3/
Id: 4/5 Title: Modulation Matrix - One Voice


Id: 5/5 Title: Modulation Matrix - One Voice

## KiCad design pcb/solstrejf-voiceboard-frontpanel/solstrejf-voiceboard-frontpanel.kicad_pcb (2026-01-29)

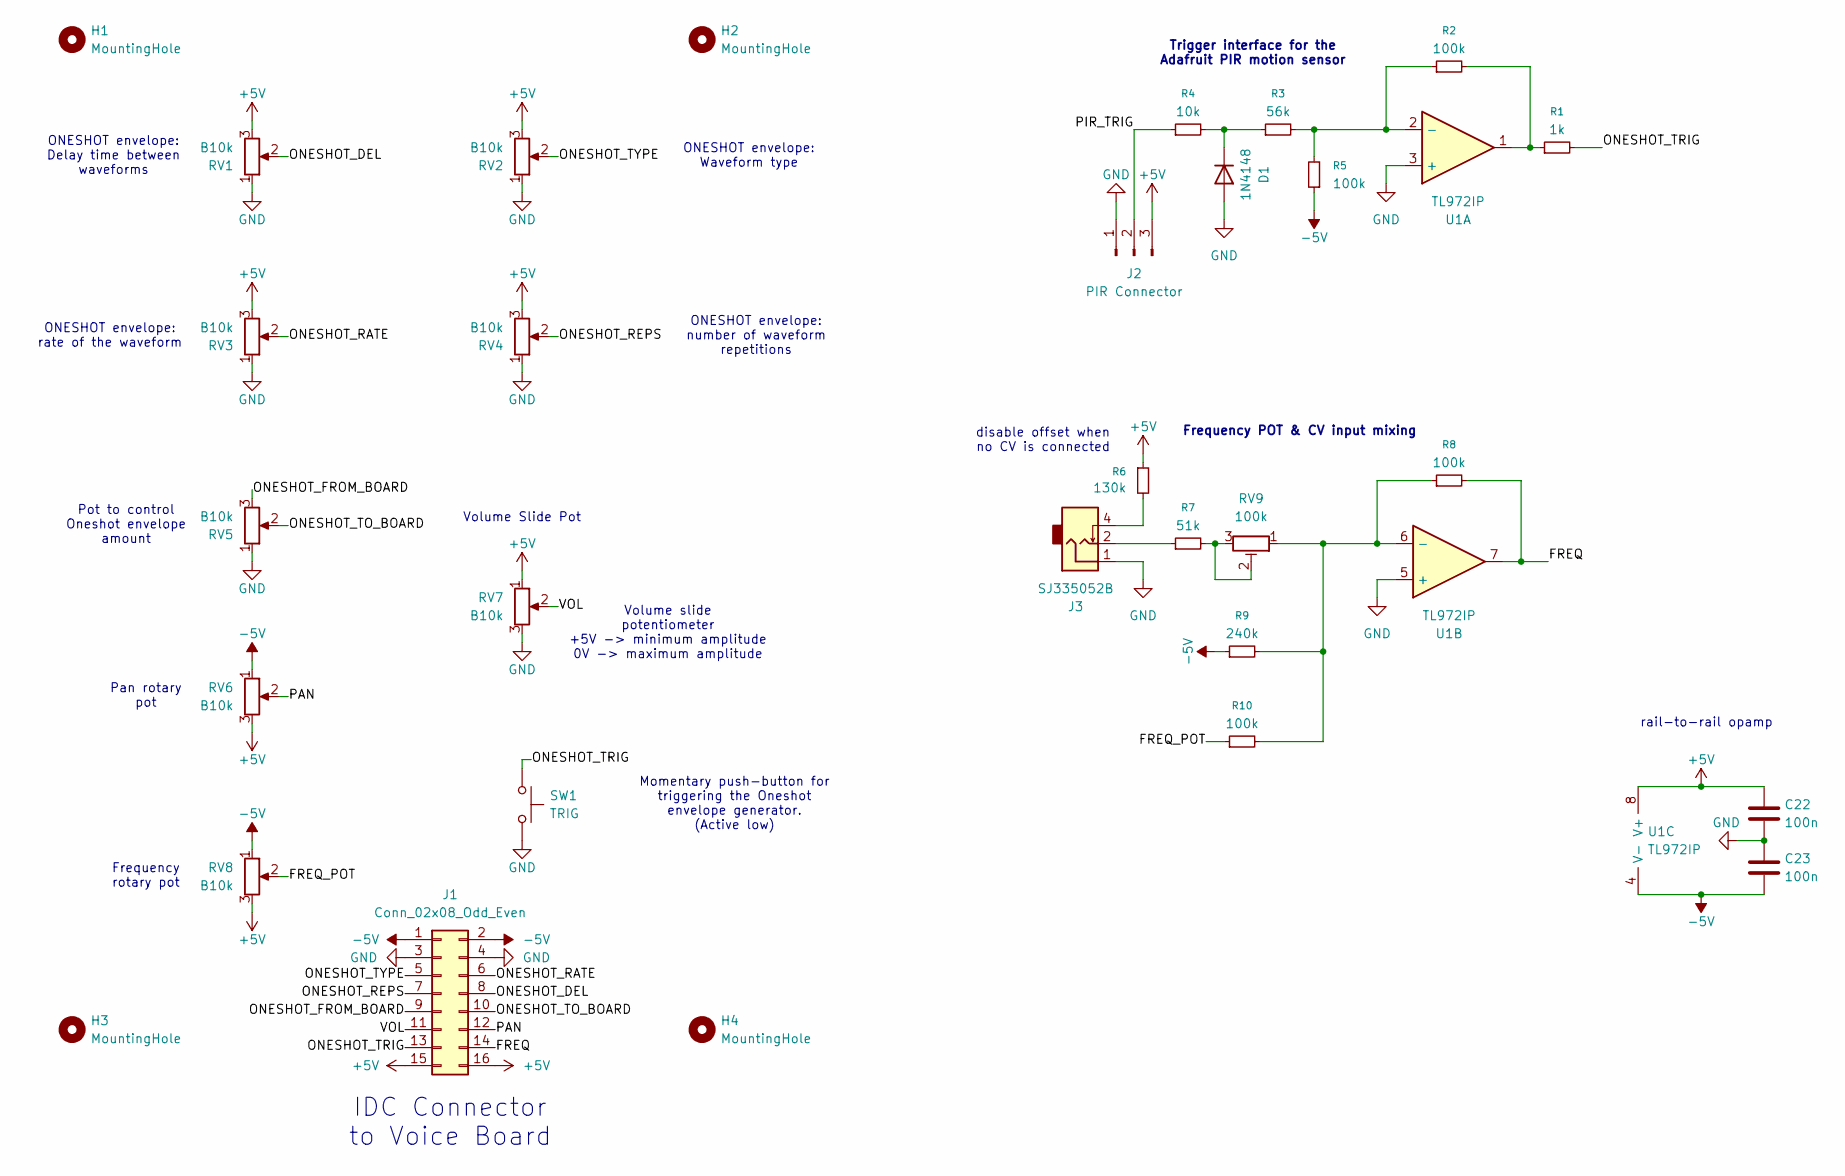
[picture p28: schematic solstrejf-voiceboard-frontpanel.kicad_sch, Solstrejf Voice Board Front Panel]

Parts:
C22, C23: 100n; C_Disc_D5.0mm_W2.5mm_P5.00mm
D1: 1N4148; D_DO-35_SOD27_P7.62mm_Horizontal
H1, H2, H3, H4: MountingHole; MountingHole_3.2mm_M3_DIN965
J1: Conn_02x08_Odd_Even; IDC-Header_2x08_P2.54mm_Vertical
J2: PIR Connector; PinHeader_1x03_P2.54mm_Vertical
J3: SJ335052B
R1: 1k; R_Axial_DIN0207_L6.3mm_D2.5mm_P10.16mm_Horizontal
R2, R5, R8, R10: 100k; R_Axial_DIN0207_L6.3mm_D2.5mm_P10.16mm_Horizontal
R3: 56k; R_Axial_DIN0207_L6.3mm_D2.5mm_P10.16mm_Horizontal
R4: 10k; R_Axial_DIN0207_L6.3mm_D2.5mm_P10.16mm_Horizontal
R6: 130k; R_Axial_DIN0207_L6.3mm_D2.5mm_P10.16mm_Horizontal
R7: 51k; R_Axial_DIN0207_L6.3mm_D2.5mm_P10.16mm_Horizontal
R9: 240k; R_Axial_DIN0207_L6.3mm_D2.5mm_P10.16mm_Horizontal
RV1, RV2, RV3, RV4, RV5, RV6, RV8: B10k; Potentiometer_Alpha_RD901F-40-00D_Single_Vertical
RV7: B10k; Potentiometer_Alpha_slide_pot_30mm
RV9: 100k; Potentiometer_Bourns_3296Y_Vertical
SW1: TRIG; SW_SPST_Omron_B3F-40xx
U1: TL972IP; DIP-8_W7.62mm_Socket

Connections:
+5V: C22.1, J1.15, J1.16, J2.3, R6.1, RV1.3, RV2.3, RV3.3, RV4.3, RV6.3, RV7.1, RV8.3, U1.8 (V+)
-5V: C23.2, J1.1, J1.2, R5.1, R9.1, RV6.1, RV8.1, U1.4 (V-)
/FREQ: J1.14, R8.2, U1.7
/FREQ_POT: R10.1, RV8.2
/ONESHOT_DEL: J1.8, RV1.2
/ONESHOT_FROM_BOARD: J1.9, RV5.3
/ONESHOT_RATE: J1.6, RV3.2
/ONESHOT_REPS: J1.7, RV4.2
/ONESHOT_TO_BOARD: J1.10, RV5.2
/ONESHOT_TRIG: J1.13, R1.2, SW1.1
/ONESHOT_TYPE: J1.5, RV2.2
/PAN: J1.12, RV6.2
/PIR_TRIG: J2.2, R4.1
/VOL: J1.11, RV7.2
GND: C22.2, C23.1, D1.2 (A), J1.3, J1.4, J2.1, J3.1, RV1.1, RV2.1, RV3.1, RV4.1, RV5.1, RV7.3, SW1.2, U1.3 (+), U1.5 (+)
unnamed: D1.1 (K), R3.1, R4.2
unnamed: J3.2, R7.1
unnamed: J3.4, R6.2
unnamed: R1.1, R2.2, U1.1
unnamed: R7.2, RV9.2, RV9.3
unnamed: R2.1, R3.2, R5.2, U1.2 (-)
unnamed: R8.1, R9.2, R10.2, RV9.1, U1.6 (-)

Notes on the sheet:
Pan rotary pot
Trigger interface for the Adafruit PIR motion sensor
ONESHOT envelope: rate of the waveform
disable offset when no CV is connected
Frequency rotary pot
Frequency POT & CV input mixing
Volume slide potentiometer +5V -> minimum amplitude 0V -> maximum amplitude
ONESHOT envelope: number of waveform repetitions
rail-to-rail opamp
IDC Connector to Voice Board
ONESHOT envelope: Waveform type
ONESHOT envelope: Delay time between waveforms
Volume Slide Pot
Pot to control Oneshot envelope amount
Momentary push-button for triggering the Oneshot envelope generator. (Active low)

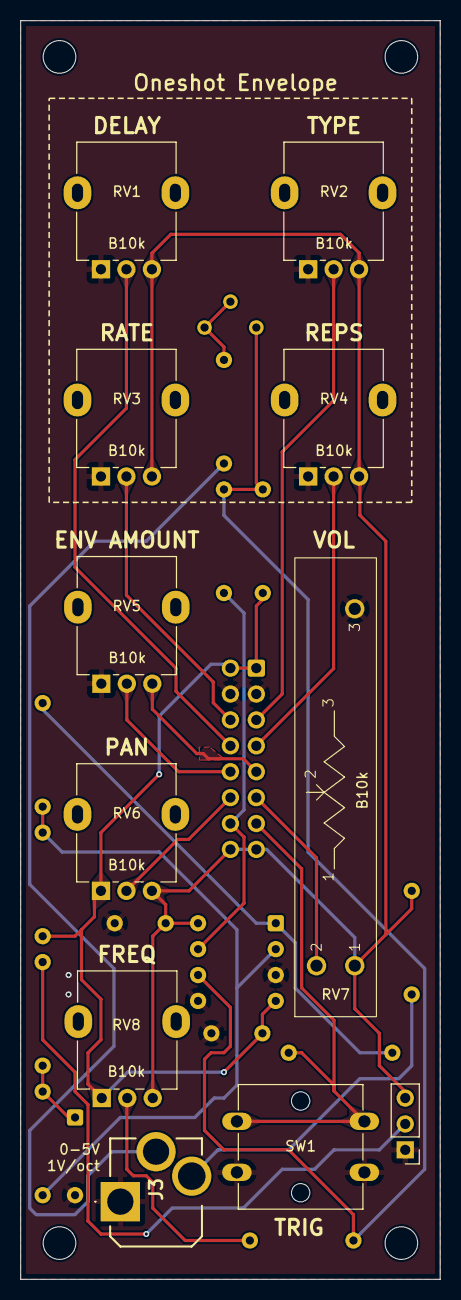
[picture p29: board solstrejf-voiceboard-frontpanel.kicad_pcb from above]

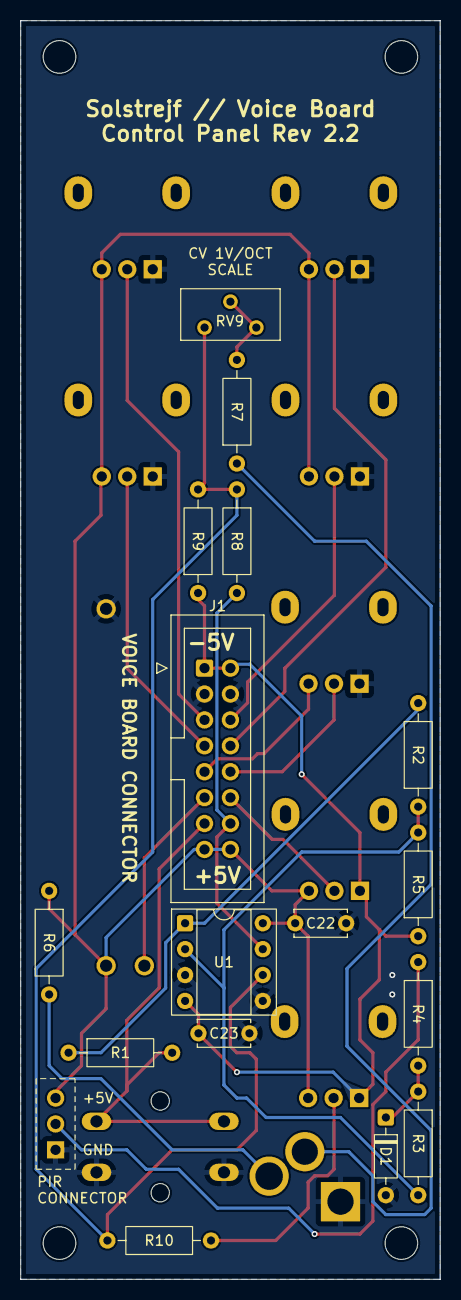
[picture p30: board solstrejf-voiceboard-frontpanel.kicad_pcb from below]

Board: 2 copper layers, 41.1 x 123.4 mm, 31 parts (16 on the bottom side), 22 nets.

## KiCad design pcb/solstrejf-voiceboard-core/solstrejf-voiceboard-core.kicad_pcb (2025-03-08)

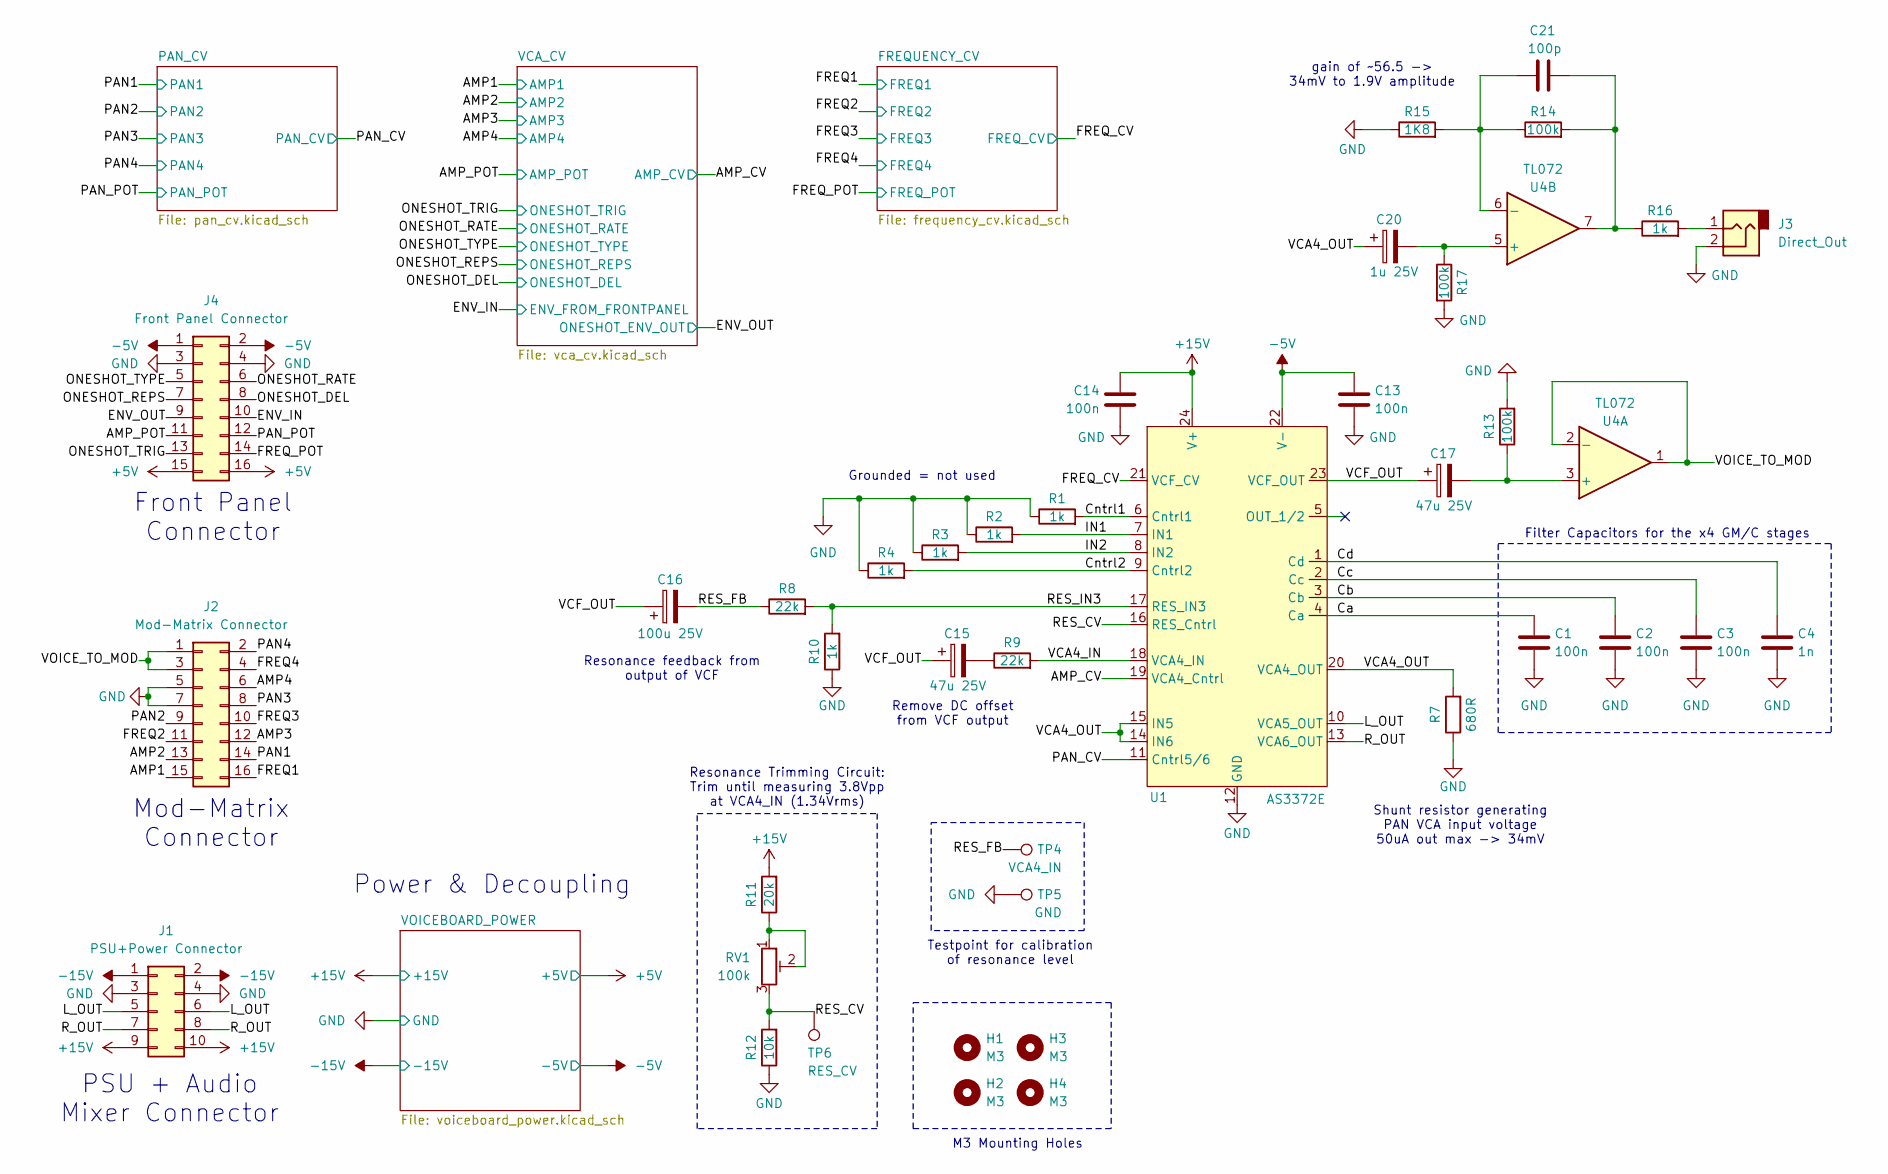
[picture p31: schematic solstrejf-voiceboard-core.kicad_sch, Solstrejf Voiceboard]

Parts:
C1, C2, C3, C13, C14: 100n; C_Disc_D5.0mm_W2.5mm_P5.00mm
C4: 1n; C_Disc_D5.0mm_W2.5mm_P5.00mm
C15, C17: 47u 25V; CP_Radial_D5.0mm_P2.50mm
C16: 100u 25V; CP_Radial_D6.3mm_P2.50mm
C20: 1u 25V; CP_Radial_D5.0mm_P2.50mm
C21: 100p; C_Disc_D5.0mm_W2.5mm_P5.00mm
H1, H2, H3, H4: M3; MountingHole_3.2mm_M3_DIN965
J1: PSU+Power Connector; IDC-Header_2x05_P2.54mm_Vertical
J2: Mod-Matrix Connector; IDC-Header_2x08_P2.54mm_Vertical
J3: Direct_Out; PinHeader_1x02_P2.54mm_Vertical
J4: Front Panel Connector; IDC-Header_2x08_P2.54mm_Vertical
R1, R2, R3, R4, R10, R16: 1k; R_Axial_DIN0207_L6.3mm_D2.5mm_P10.16mm_Horizontal
R7: 680R; R_Axial_DIN0207_L6.3mm_D2.5mm_P10.16mm_Horizontal
R8, R9: 22k; R_Axial_DIN0207_L6.3mm_D2.5mm_P10.16mm_Horizontal
R11: 20k; R_Axial_DIN0207_L6.3mm_D2.5mm_P10.16mm_Horizontal
R12: 10k; R_Axial_DIN0207_L6.3mm_D2.5mm_P10.16mm_Horizontal
R13, R14, R17: 100k; R_Axial_DIN0207_L6.3mm_D2.5mm_P10.16mm_Horizontal
R15: 1K8; R_Axial_DIN0207_L6.3mm_D2.5mm_P10.16mm_Horizontal
RV1: 100k; Potentiometer_Bourns_3296Y_Vertical
TP4: VCA4_IN; TestPoint_Loop_D2.50mm_Drill1.0mm
TP5: GND; TestPoint_Loop_D2.50mm_Drill1.0mm
TP6: RES_CV; TestPoint_Loop_D2.50mm_Drill1.0mm
U1: AS3372E; DIP-24_W7.62mm_Socket
U4: TL072; DIP-8_W7.62mm_Socket

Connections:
+5V: J4.15, J4.16; also elsewhere on the board
+15V: C14.1, J1.9, J1.10, R11.2, U1.24 (V+); also elsewhere on the board
-5V: C13.1, J4.1, J4.2, U1.22 (V-); also elsewhere on the board
-15V: J1.1, J1.2; also elsewhere on the board
/AMP1: J2.15; also elsewhere on the board
/AMP2: J2.13; also elsewhere on the board
/AMP3: J2.12; also elsewhere on the board
/AMP4: J2.6; also elsewhere on the board
/AMP_CV: U1.19 (VCA4_Cntrl); also elsewhere on the board
/AMP_POT: J4.11; also elsewhere on the board
/Ca: C1.1, U1.4 (Ca)
/Cb: C2.1, U1.3 (Cb)
/Cc: C3.1, U1.2 (Cc)
/Cd: C4.1, U1.1 (Cd)
/Cntrl1: R1.2, U1.6 (Cntrl1)
/Cntrl2: R4.2, U1.9 (Cntrl2)
/ENV_IN: J4.10; also elsewhere on the board
/ENV_OUT: J4.9; also elsewhere on the board
/FREQ1: J2.16; also elsewhere on the board
/FREQ2: J2.11; also elsewhere on the board
/FREQ3: J2.10; also elsewhere on the board
/FREQ4: J2.4; also elsewhere on the board
/FREQ_CV: U1.21 (VCF_CV); also elsewhere on the board
/FREQ_POT: J4.14; also elsewhere on the board
/IN1: R2.2, U1.7 (IN1)
/IN2: R3.2, U1.8 (IN2)
/L_OUT: J1.5, J1.6, U1.10 (VCA5_OUT)
/ONESHOT_DEL: J4.8; also elsewhere on the board
/ONESHOT_RATE: J4.6; also elsewhere on the board
/ONESHOT_REPS: J4.7; also elsewhere on the board
/ONESHOT_TRIG: J4.13; also elsewhere on the board
/ONESHOT_TYPE: J4.5; also elsewhere on the board
/PAN1: J2.14; also elsewhere on the board
/PAN2: J2.9; also elsewhere on the board
/PAN3: J2.8; also elsewhere on the board
/PAN4: J2.2; also elsewhere on the board
/PAN_CV: U1.11 (Cntrl5/6); also elsewhere on the board
/PAN_POT: J4.12; also elsewhere on the board
/RES_CV: R12.2, RV1.3, TP6.1, U1.16 (RES_Cntrl)
/RES_FB: C16.2, R8.1, TP4.1
/RES_IN3: R8.2, R10.2, U1.17 (RES_IN3)
/R_OUT: J1.7, J1.8, U1.13 (VCA6_OUT)
/VCA4_IN: R9.2, U1.18 (VCA4_IN)
/VCA4_OUT: C20.1, R7.2, U1.14 (IN6), U1.15 (IN5), U1.20 (VCA4_OUT)
/VCF_OUT: C15.1, C16.1, C17.1, U1.23 (VCF_OUT)
/VOICE_TO_MOD: J2.1, J2.3, U4.1, U4.2 (-)
GND: C1.2, C2.2, C3.2, C4.2, C13.2, C14.2, J1.3, J1.4, J2.5, J2.7, J3.2, J4.3, J4.4, R1.1, R2.1, R3.1, R4.1, R7.1, R10.1, R12.1, R13.2, R15.1, R17.2, TP5.1, U1.12 (GND); also elsewhere on the board
unnamed: C15.2, R9.1
unnamed: C21.2, R14.2, R16.1, U4.7
unnamed: J3.1, R16.2
unnamed: R11.1, RV1.1, RV1.2
unnamed: C17.2, R13.1, U4.3 (+)
unnamed: C20.2, R17.1, U4.5 (+)
unnamed: C21.1, R14.1, R15.2, U4.6 (-)

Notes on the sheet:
Resonance feedback from output of VCF
Shunt resistor generating PAN VCA input voltage 50uA out max -> 34mV
M3 Mounting Holes
Grounded = not used
gain of ~56.5 -> 34mV to 1.9V amplitude
Mod-Matrix Connector
Front Panel Connector
PSU + Audio Mixer Connector
Power & Decoupling
Remove DC offset from VCF output
Testpoint for calibration of resonance level
Filter Capacitors for the x4 GM/C stages
Resonance Trimming Circuit: Trim until measuring 3.8Vpp at VCA4_IN (1.34Vrms)

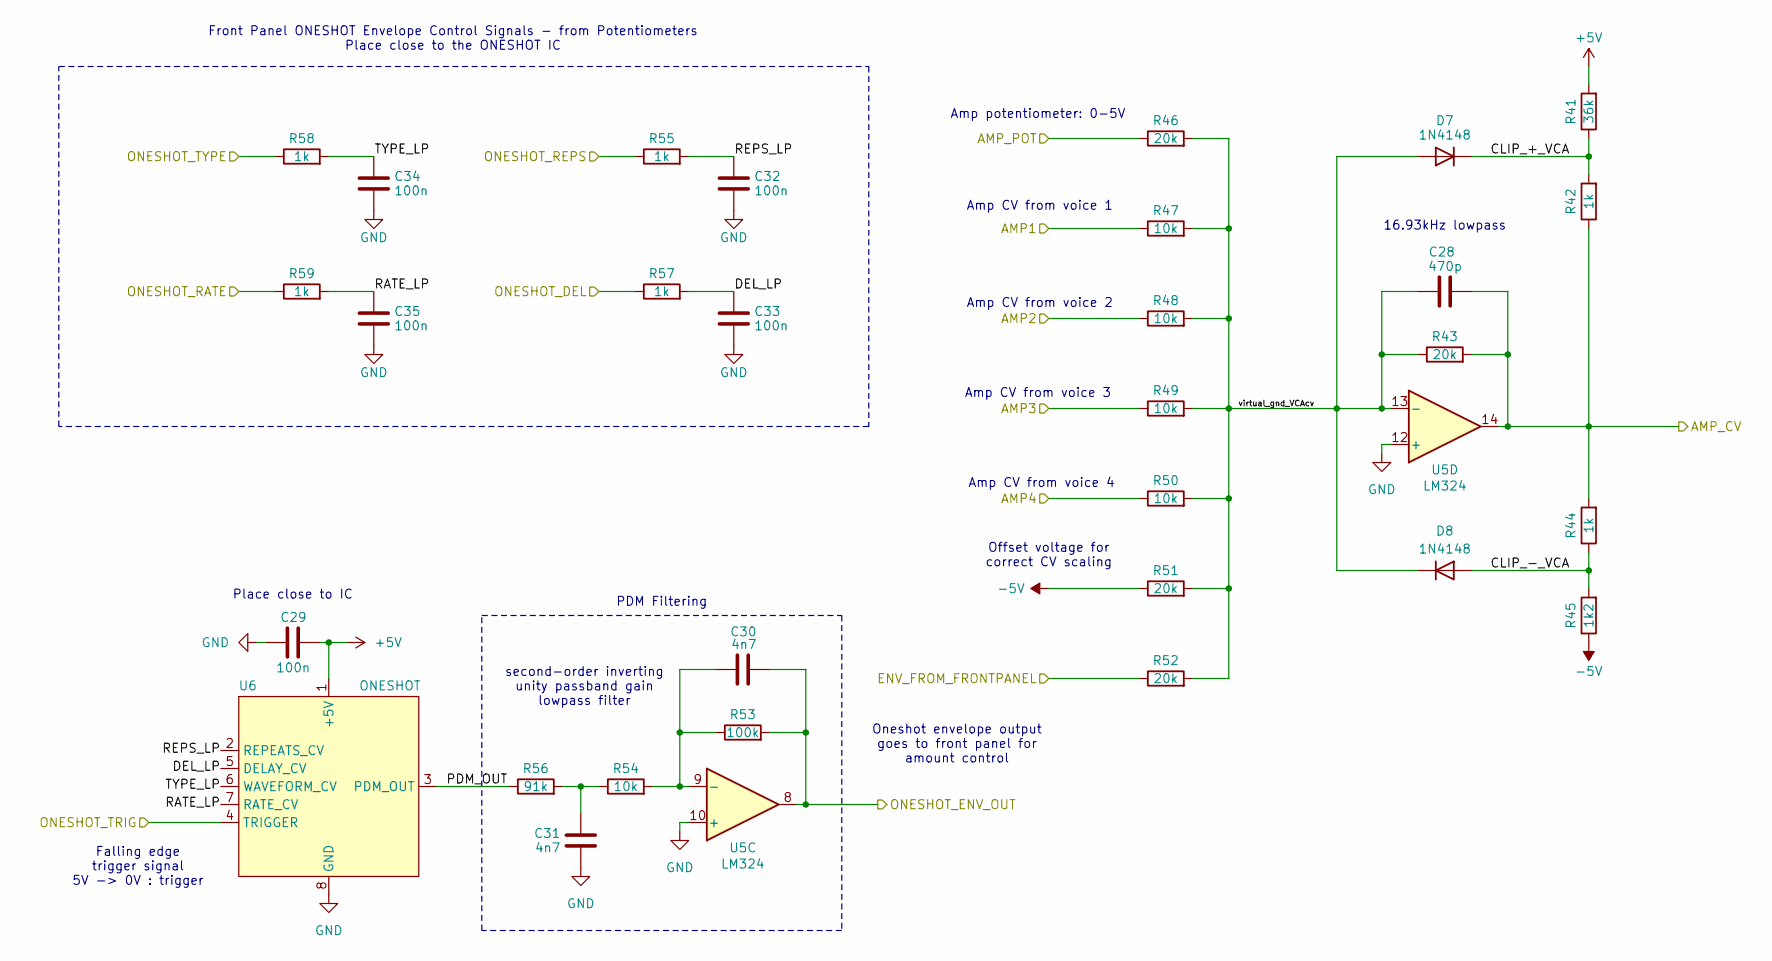
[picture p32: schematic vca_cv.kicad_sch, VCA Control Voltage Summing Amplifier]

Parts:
C28: 470p; C_Disc_D5.0mm_W2.5mm_P5.00mm
C29, C32, C33, C34, C35: 100n; C_Disc_D5.0mm_W2.5mm_P5.00mm
C30, C31: 4n7; C_Disc_D5.0mm_W2.5mm_P5.00mm
D7, D8: 1N4148; D_DO-35_SOD27_P7.62mm_Horizontal
R41: 36k; R_Axial_DIN0207_L6.3mm_D2.5mm_P10.16mm_Horizontal
R42, R44, R55, R57, R58, R59: 1k; R_Axial_DIN0207_L6.3mm_D2.5mm_P10.16mm_Horizontal
R43, R46, R51, R52: 20k; R_Axial_DIN0207_L6.3mm_D2.5mm_P10.16mm_Horizontal
R45: 1k2; R_Axial_DIN0207_L6.3mm_D2.5mm_P10.16mm_Horizontal
R47, R48, R49, R50, R54: 10k; R_Axial_DIN0207_L6.3mm_D2.5mm_P10.16mm_Horizontal
R53: 100k; R_Axial_DIN0207_L6.3mm_D2.5mm_P10.16mm_Horizontal
R56: 91k; R_Axial_DIN0207_L6.3mm_D2.5mm_P10.16mm_Horizontal
U5: LM324; DIP-14_W7.62mm
U6: ONESHOT; DIP-8_W7.62mm_Socket

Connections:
+5V: C29.2, R41.2, U6.1 (+5V); also elsewhere on the board
-5V: R45.1, R51.1; also elsewhere on the board
/AMP1: R47.1; also elsewhere on the board
/AMP2: R48.1; also elsewhere on the board
/AMP3: R49.1; also elsewhere on the board
/AMP4: R50.1; also elsewhere on the board
/AMP_CV: C28.2, R42.1, R43.2, R44.2, U5.14; also elsewhere on the board
/AMP_POT: R46.1; also elsewhere on the board
/ENV_IN: R52.1; also elsewhere on the board
/ENV_OUT: C30.2, R53.2, U5.8; also elsewhere on the board
/ONESHOT_DEL: R57.1; also elsewhere on the board
/ONESHOT_RATE: R59.1; also elsewhere on the board
/ONESHOT_REPS: R55.1; also elsewhere on the board
/ONESHOT_TRIG: U6.4 (TRIGGER); also elsewhere on the board
/ONESHOT_TYPE: R58.1; also elsewhere on the board
/VCA_CV/CLIP_+_VCA: D7.1 (K), R41.1, R42.2
/VCA_CV/CLIP_-_VCA: D8.2 (A), R44.1, R45.2
/VCA_CV/DEL_LP: C33.2, R57.2, U6.5 (DELAY_CV)
/VCA_CV/PDM_OUT: R56.1, U6.3 (PDM_OUT)
/VCA_CV/RATE_LP: C35.2, R59.2, U6.7 (RATE_CV)
/VCA_CV/REPS_LP: C32.2, R55.2, U6.2 (REPEATS_CV)
/VCA_CV/TYPE_LP: C34.2, R58.2, U6.6 (WAVEFORM_CV)
/VCA_CV/virtual_gnd_VCAcv: C28.1, D7.2 (A), D8.1 (K), R43.1, R46.2, R47.2, R48.2, R49.2, R50.2, R51.2, R52.2, U5.13 (-)
GND: C29.1, C31.1, C32.1, C33.1, C34.1, C35.1, U5.10 (+), U5.12 (+), U6.8 (GND); also elsewhere on the board
unnamed: C31.2, R54.1, R56.2
unnamed: C30.1, R53.1, R54.2, U5.9 (-)

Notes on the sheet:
Amp CV from voice 1
Offset voltage for correct CV scaling
Oneshot envelope output goes to front panel for amount control
Amp CV from voice 2
PDM Filtering
Place close to IC
Amp potentiometer: 0-5V
Falling edge trigger signal 5V -> 0V : trigger
16.93kHz lowpass
second-order inverting unity passband gain lowpass filter
Front Panel ONESHOT Envelope Control Signals - from Potentiometers Place close to the ONESHOT IC
Amp CV from voice 3
Amp CV from voice 4

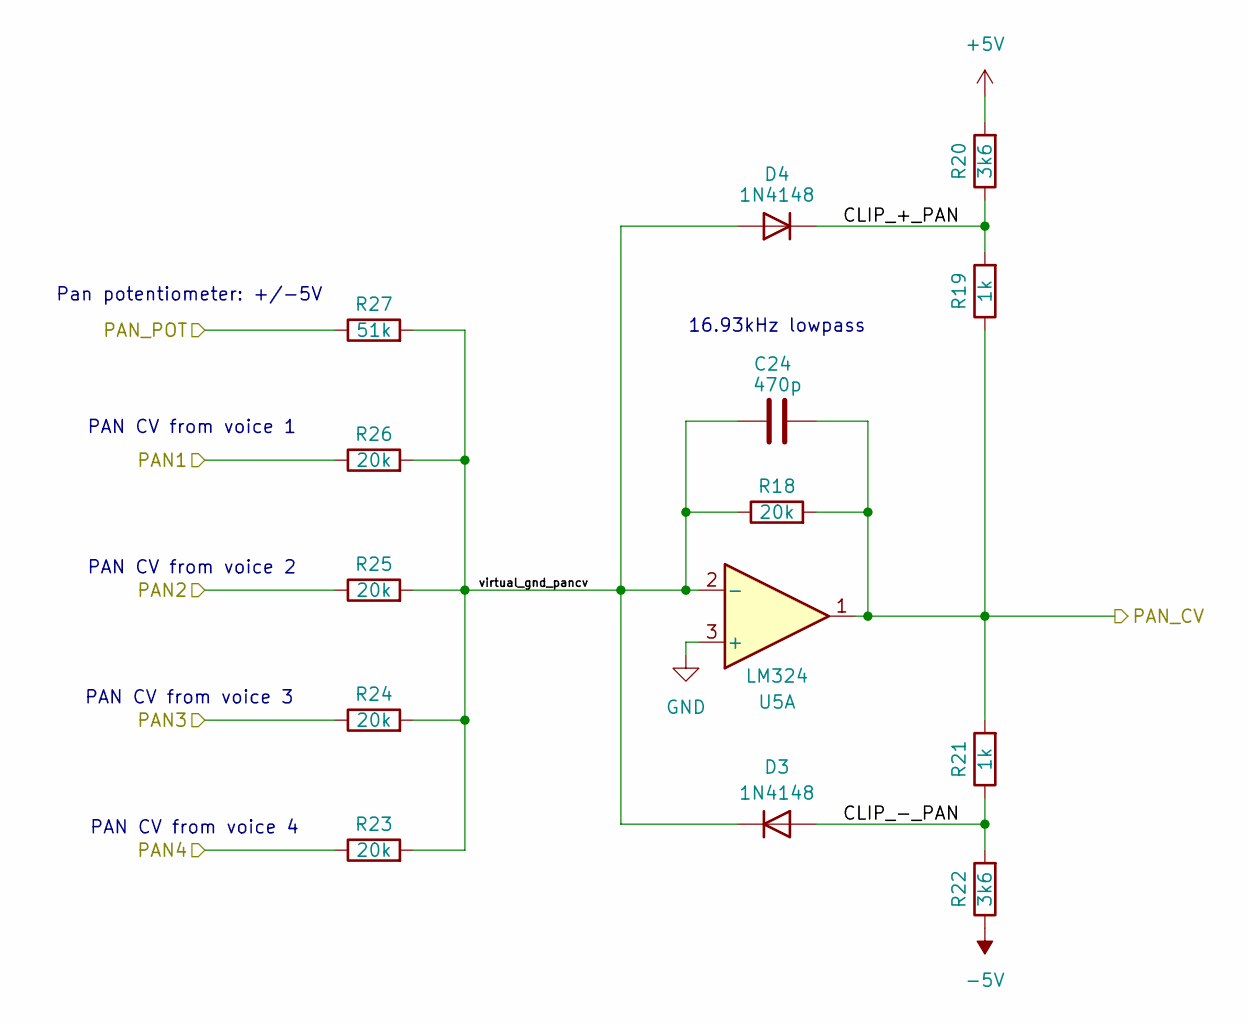
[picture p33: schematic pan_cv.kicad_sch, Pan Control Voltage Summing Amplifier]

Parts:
C24: 470p; C_Disc_D5.0mm_W2.5mm_P5.00mm
D3, D4: 1N4148; D_DO-35_SOD27_P7.62mm_Horizontal
R18, R23, R24, R25, R26: 20k; R_Axial_DIN0207_L6.3mm_D2.5mm_P10.16mm_Horizontal
R19, R21: 1k; R_Axial_DIN0207_L6.3mm_D2.5mm_P10.16mm_Horizontal
R20, R22: 3k6; R_Axial_DIN0207_L6.3mm_D2.5mm_P10.16mm_Horizontal
R27: 51k; R_Axial_DIN0207_L6.3mm_D2.5mm_P10.16mm_Horizontal
U5: LM324; DIP-14_W7.62mm

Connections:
+5V: R20.2; also elsewhere on the board
-5V: R22.1; also elsewhere on the board
/PAN1: R26.1; also elsewhere on the board
/PAN2: R25.1; also elsewhere on the board
/PAN3: R24.1; also elsewhere on the board
/PAN4: R23.1; also elsewhere on the board
/PAN_CV: C24.2, R18.2, R19.1, R21.2, U5.1; also elsewhere on the board
/PAN_CV/CLIP_+_PAN: D4.1 (K), R19.2, R20.1
/PAN_CV/CLIP_-_PAN: D3.2 (A), R21.1, R22.2
/PAN_CV/virtual_gnd_pancv: C24.1, D3.1 (K), D4.2 (A), R18.1, R23.2, R24.2, R25.2, R26.2, R27.2, U5.2 (-)
/PAN_POT: R27.1; also elsewhere on the board
GND: U5.3 (+); also elsewhere on the board

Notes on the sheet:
PAN CV from voice 3
PAN CV from voice 1
Pan potentiometer: +/-5V
16.93kHz lowpass
PAN CV from voice 2
PAN CV from voice 4

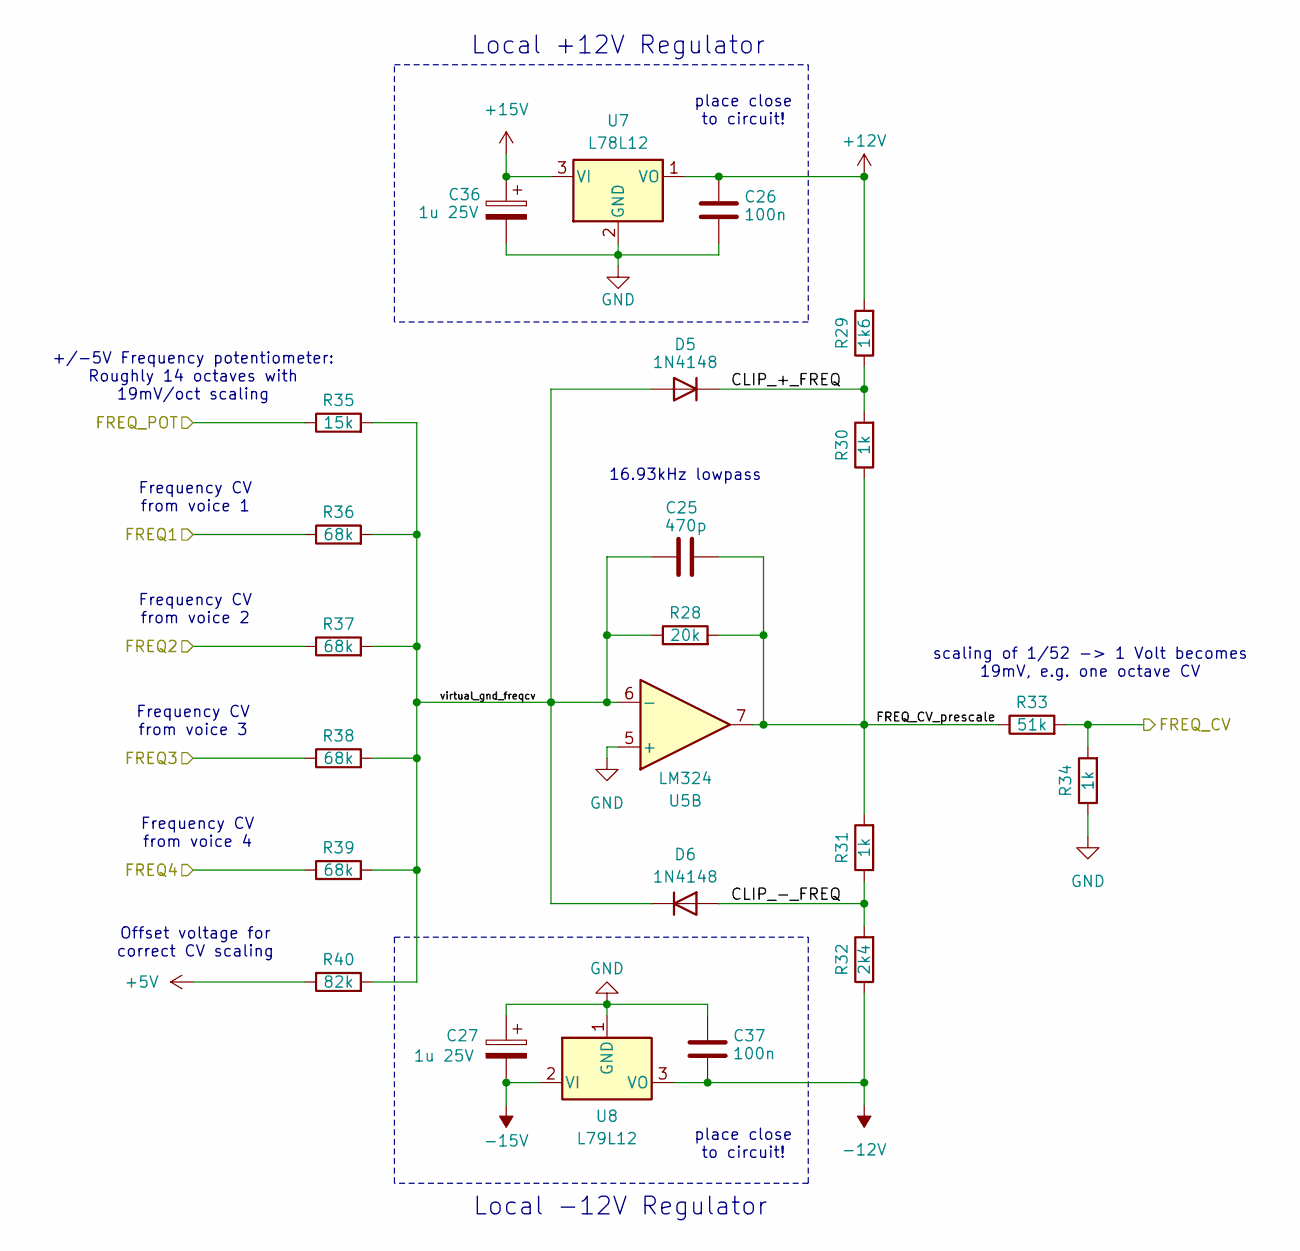
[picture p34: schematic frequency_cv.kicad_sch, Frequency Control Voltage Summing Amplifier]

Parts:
C25: 470p; C_Disc_D5.0mm_W2.5mm_P5.00mm
C26, C37: 100n; C_Disc_D5.0mm_W2.5mm_P5.00mm
C27, C36: 1u 25V; CP_Radial_D5.0mm_P2.50mm
D5, D6: 1N4148; D_DO-35_SOD27_P7.62mm_Horizontal
R28: 20k; R_Axial_DIN0207_L6.3mm_D2.5mm_P10.16mm_Horizontal
R29: 1k6; R_Axial_DIN0207_L6.3mm_D2.5mm_P10.16mm_Horizontal
R30, R31, R34: 1k; R_Axial_DIN0207_L6.3mm_D2.5mm_P10.16mm_Horizontal
R32: 2k4; R_Axial_DIN0207_L6.3mm_D2.5mm_P10.16mm_Horizontal
R33: 51k; R_Axial_DIN0207_L6.3mm_D2.5mm_P10.16mm_Horizontal
R35: 15k; R_Axial_DIN0207_L6.3mm_D2.5mm_P10.16mm_Horizontal
R36, R37, R38, R39: 68k; R_Axial_DIN0207_L6.3mm_D2.5mm_P10.16mm_Horizontal
R40: 82k; R_Axial_DIN0207_L6.3mm_D2.5mm_P10.16mm_Horizontal
U5: LM324; DIP-14_W7.62mm
U7: L78L12; TO-92_Inline
U8: L79L12; TO-92_Inline

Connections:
+5V: R40.1; also elsewhere on the board
+12V: C26.2, R29.2, U7.1 (VO)
+15V: C36.1, U7.3 (VI); also elsewhere on the board
-12V: C37.1, R32.1, U8.3 (VO)
-15V: C27.2, U8.2 (VI); also elsewhere on the board
/FREQ1: R36.1; also elsewhere on the board
/FREQ2: R37.1; also elsewhere on the board
/FREQ3: R38.1; also elsewhere on the board
/FREQ4: R39.1; also elsewhere on the board
/FREQUENCY_CV/CLIP_+_FREQ: D5.1 (K), R29.1, R30.2
/FREQUENCY_CV/CLIP_-_FREQ: D6.2 (A), R31.1, R32.2
/FREQUENCY_CV/FREQ_CV_prescale: C25.2, R28.2, R30.1, R31.2, R33.1, U5.7
/FREQUENCY_CV/virtual_gnd_freqcv: C25.1, D5.2 (A), D6.1 (K), R28.1, R35.2, R36.2, R37.2, R38.2, R39.2, R40.2, U5.6 (-)
/FREQ_CV: R33.2, R34.2; also elsewhere on the board
/FREQ_POT: R35.1; also elsewhere on the board
GND: C26.1, C27.1, C36.2, C37.2, R34.1, U5.5 (+), U7.2 (GND), U8.1 (GND); also elsewhere on the board

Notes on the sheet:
Offset voltage for correct CV scaling
Local +12V Regulator
16.93kHz lowpass
Frequency CV from voice 3
scaling of 1/52 -> 1 Volt becomes 19mV, e.g. one octave CV
Frequency CV from voice 2
Frequency CV from voice 1
place close to circuit!
Frequency CV from voice 4
Local -12V Regulator
+/-5V Frequency potentiometer: Roughly 14 octaves with 19mV/oct scaling

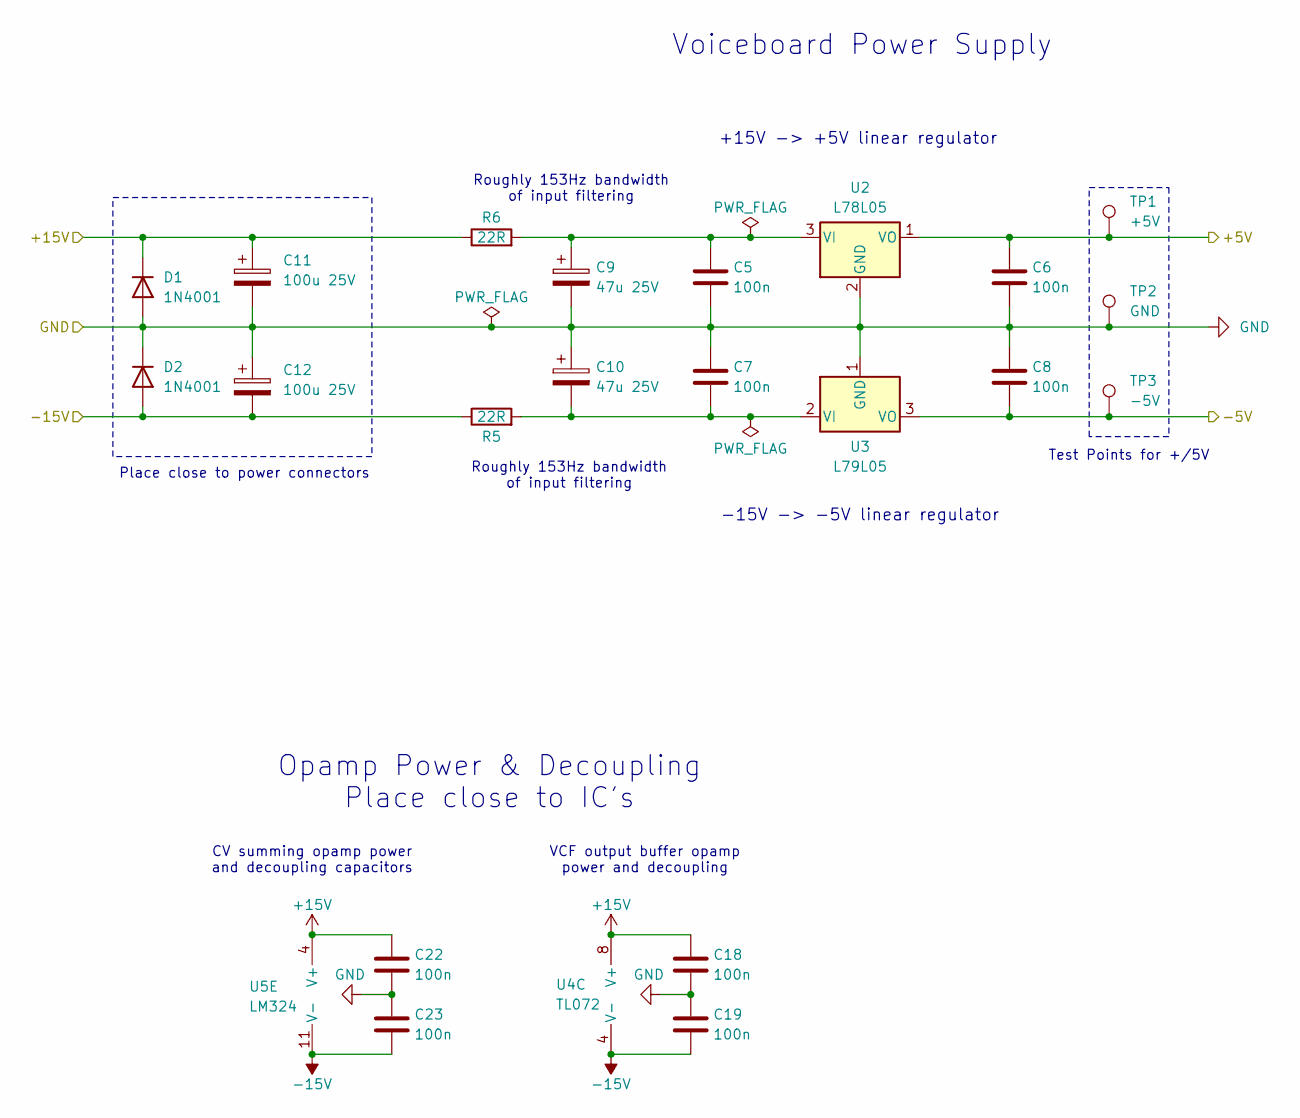
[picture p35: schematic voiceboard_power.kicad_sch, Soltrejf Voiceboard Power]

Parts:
C5, C6, C7, C8, C18, C19, C22, C23: 100n; C_Disc_D5.0mm_W2.5mm_P5.00mm
C9, C10: 47u 25V; CP_Radial_D5.0mm_P2.50mm
C11, C12: 100u 25V; CP_Radial_D6.3mm_P2.50mm
D1, D2: 1N4001; D_DO-41_SOD81_P10.16mm_Horizontal
R5, R6: 22R; R_Axial_DIN0207_L6.3mm_D2.5mm_P10.16mm_Horizontal
TP1: +5V; TestPoint_Loop_D2.50mm_Drill1.0mm
TP2: GND; TestPoint_Loop_D2.50mm_Drill1.0mm
TP3: -5V; TestPoint_Loop_D2.50mm_Drill1.0mm
U2: L78L05; TO-92_Inline
U3: L79L05; TO-92_Inline
U4: TL072; DIP-8_W7.62mm_Socket
U5: LM324; DIP-14_W7.62mm

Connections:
+5V: C6.1, TP1.1, U2.1 (VO); also elsewhere on the board
+15V: C11.1, C18.1, C22.1, D1.1 (K), R6.1, U4.8 (V+), U5.4 (V+); also elsewhere on the board
-5V: C8.2, TP3.1, U3.3 (VO); also elsewhere on the board
-15V: C12.2, C19.2, C23.2, D2.2 (A), R5.1, U4.4 (V-), U5.11 (V-); also elsewhere on the board
GND: C5.2, C6.2, C7.1, C8.1, C9.2, C10.1, C11.2, C12.1, C18.2, C19.1, C22.2, C23.1, D1.2 (A), D2.1 (K), TP2.1, U2.2 (GND), U3.1 (GND); also elsewhere on the board
unnamed: C5.1, C9.1, R6.2, U2.3 (VI)
unnamed: C7.2, C10.2, R5.2, U3.2 (VI)

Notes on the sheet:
-15V -> -5V linear regulator
VCF output buffer opamp power and decoupling
+15V -> +5V linear regulator
Opamp Power & Decoupling Place close to IC's
Place close to power connectors
CV summing opamp power and decoupling capacitors
Roughly 153Hz bandwidth of input filtering
Test Points for +/5V
Voiceboard Power Supply

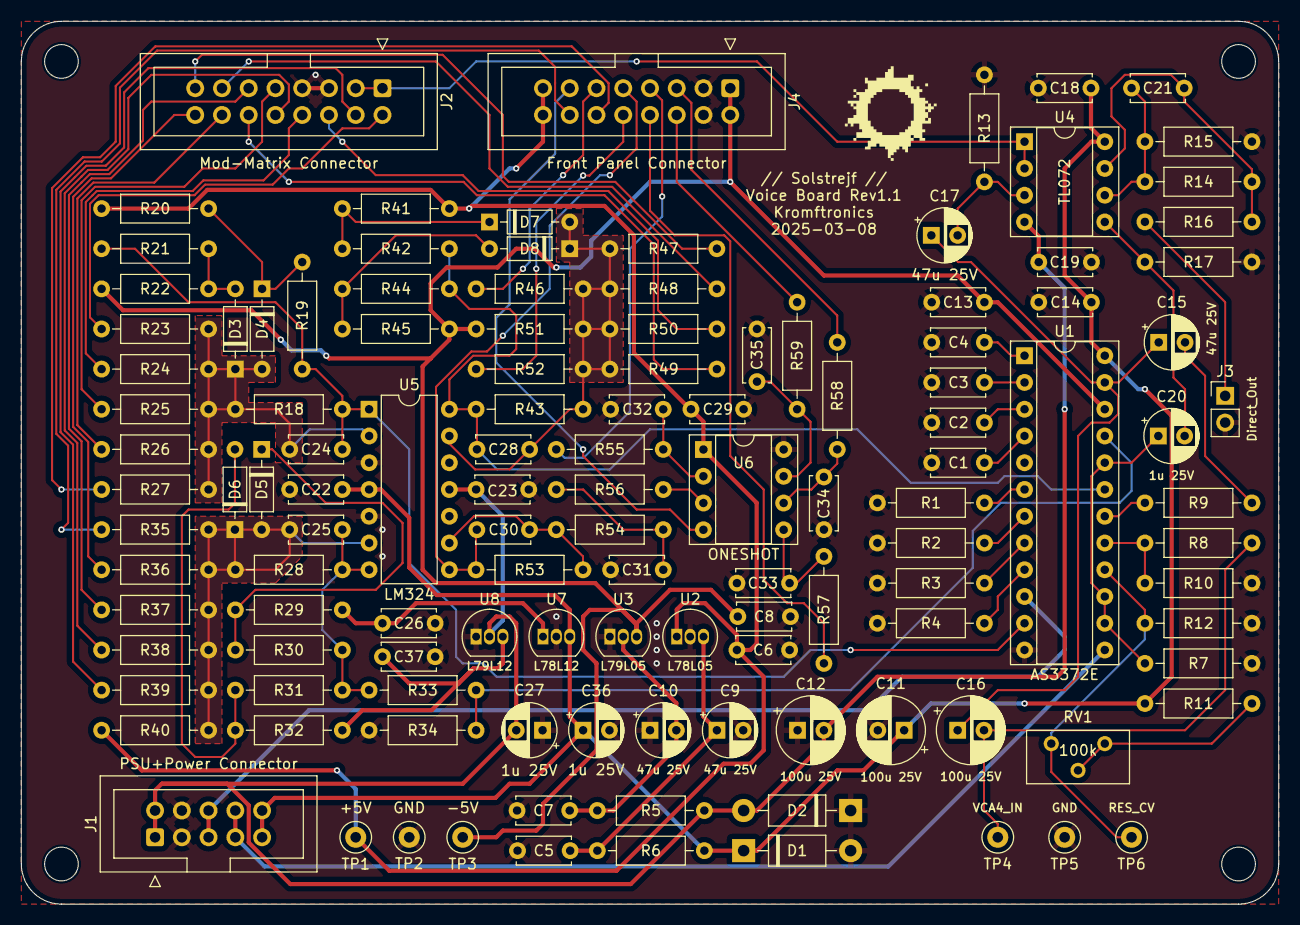
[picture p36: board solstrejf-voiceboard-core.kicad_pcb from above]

Board: 2 copper layers, 119.4 x 83.8 mm, 127 parts (0 on the bottom side), 75 nets.

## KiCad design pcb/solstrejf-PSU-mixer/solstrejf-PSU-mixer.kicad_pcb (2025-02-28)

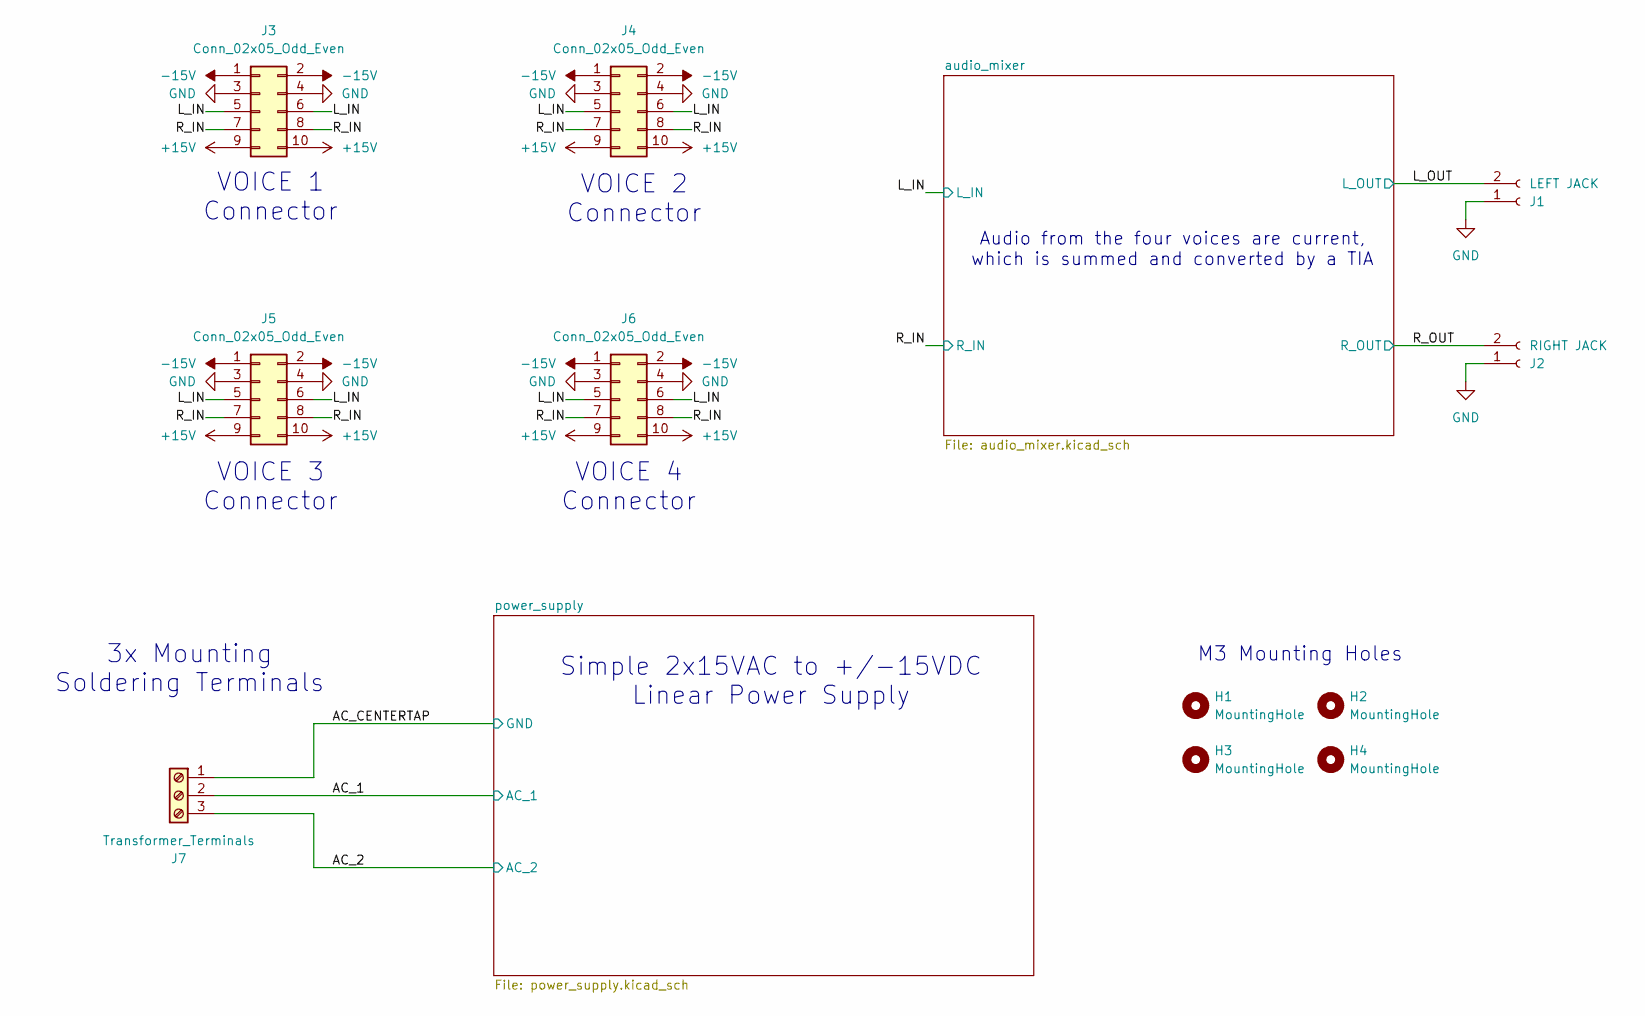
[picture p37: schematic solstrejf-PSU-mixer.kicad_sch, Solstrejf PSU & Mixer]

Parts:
H1, H2, H3, H4: MountingHole; MountingHole_3.2mm_M3_DIN965
J1: LEFT JACK; PinHeader_1x02_P2.54mm_Vertical
J2: RIGHT JACK; PinHeader_1x02_P2.54mm_Vertical
J3, J4, J5, J6: Conn_02x05_Odd_Even; IDC-Header_2x05_P2.54mm_Vertical
J7: Transformer_Terminals; SolderWire-0.5sqmm_1x03_P4.8mm_D0.9mm_OD2.3mm

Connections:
+15V: J3.9, J3.10, J4.9, J4.10, J5.9, J5.10, J6.9, J6.10; also elsewhere on the board
-15V: J3.1, J3.2, J4.1, J4.2, J5.1, J5.2, J6.1, J6.2; also elsewhere on the board
/AC_1: J7.2; also elsewhere on the board
/AC_2: J7.3; also elsewhere on the board
/L_IN: J3.5, J3.6, J4.5, J4.6, J5.5, J5.6, J6.5, J6.6; also elsewhere on the board
/L_OUT: J1.2; also elsewhere on the board
/R_IN: J3.7, J3.8, J4.7, J4.8, J5.7, J5.8, J6.7, J6.8; also elsewhere on the board
/R_OUT: J2.2; also elsewhere on the board
GND: J1.1, J2.1, J3.3, J3.4, J4.3, J4.4, J5.3, J5.4, J6.3, J6.4, J7.1; also elsewhere on the board

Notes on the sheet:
Audio from the four voices are current, which is summed and converted by a TIA
Simple 2x15VAC to +/-15VDC Linear Power Supply
M3 Mounting Holes
3x Mounting Soldering Terminals
VOICE 2 Connector
VOICE 1 Connector
VOICE 4 Connector
VOICE 3 Connector

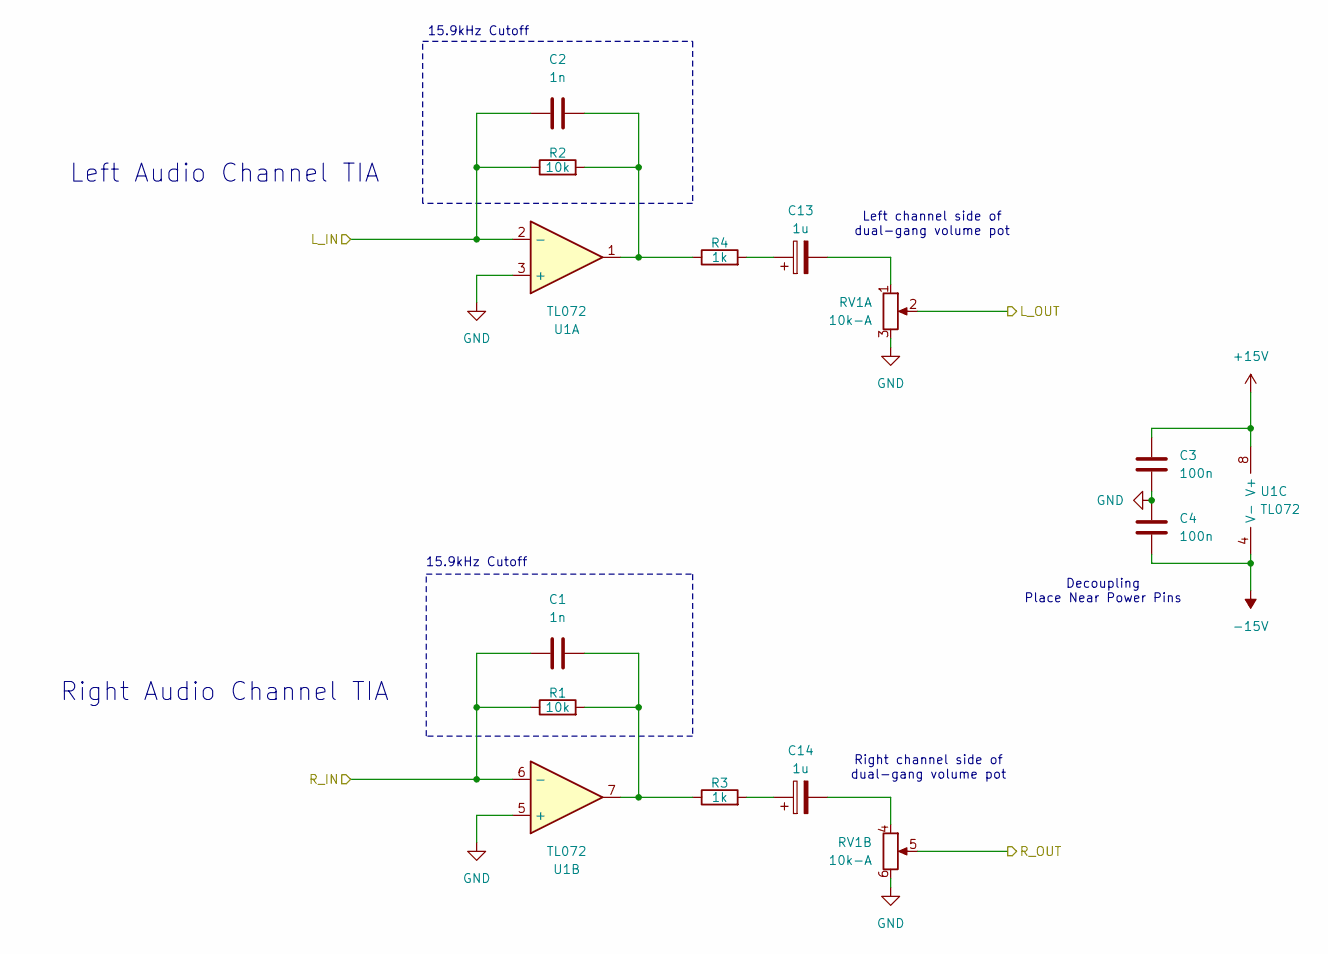
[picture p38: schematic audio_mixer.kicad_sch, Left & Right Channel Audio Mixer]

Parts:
C1, C2: 1n; C_Disc_D5.0mm_W2.5mm_P5.00mm
C3, C4: 100n; C_Disc_D5.0mm_W2.5mm_P5.00mm
C13, C14: 1u; CP_Radial_D5.0mm_P2.00mm
R1, R2: 10k; R_Axial_DIN0207_L6.3mm_D2.5mm_P10.16mm_Horizontal
R3, R4: 1k; R_Axial_DIN0207_L6.3mm_D2.5mm_P10.16mm_Horizontal
RV1: 10k-A; PinHeader_2x03_P2.54mm_Vertical
U1: TL072; DIP-8_W7.62mm

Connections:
+15V: C3.2, U1.8 (V+); also elsewhere on the board
-15V: C4.1, U1.4 (V-); also elsewhere on the board
/L_IN: C2.1, R2.1, U1.2 (-); also elsewhere on the board
/L_OUT: RV1.2; also elsewhere on the board
/R_IN: C1.1, R1.1, U1.6 (-); also elsewhere on the board
/R_OUT: RV1.5; also elsewhere on the board
GND: C3.1, C4.2, RV1.3, RV1.6, U1.3 (+), U1.5 (+); also elsewhere on the board
unnamed: C1.2, R1.2, R3.1, U1.7
unnamed: C2.2, R2.2, R4.1, U1.1
unnamed: C13.1, R4.2
unnamed: C13.2, RV1.1
unnamed: C14.1, R3.2
unnamed: C14.2, RV1.4

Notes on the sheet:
Decoupling Place Near Power Pins
Left Audio Channel TIA
15.9kHz Cutoff
Right Audio Channel TIA
Right channel side of dual-gang volume pot
Left channel side of dual-gang volume pot

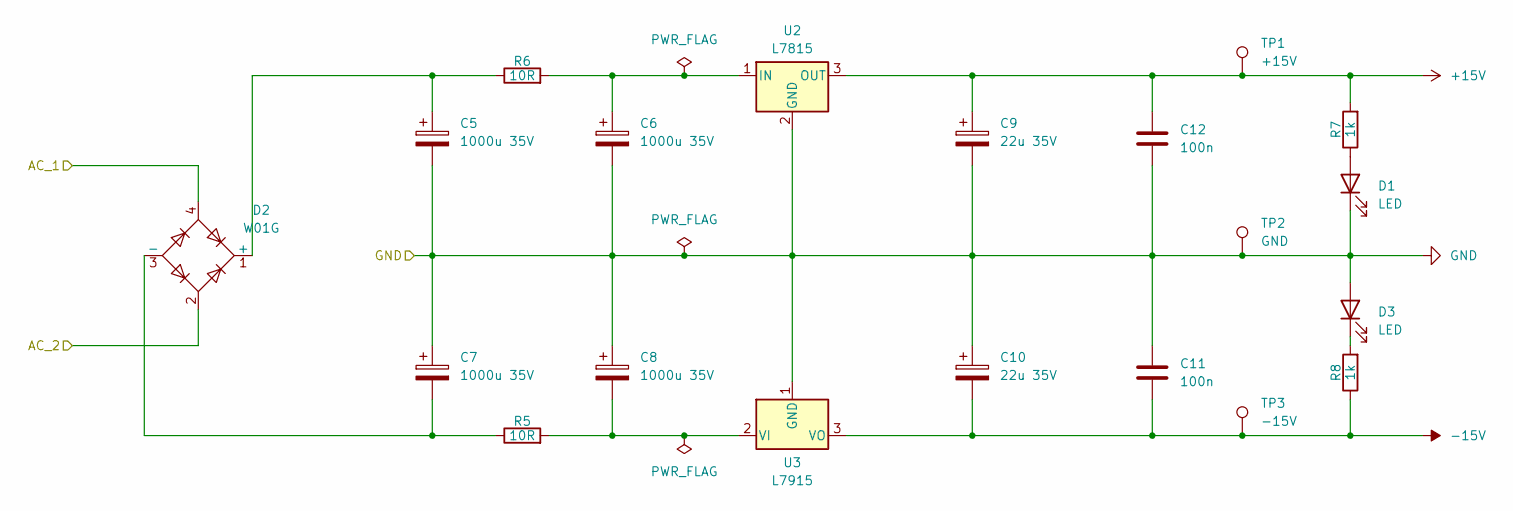
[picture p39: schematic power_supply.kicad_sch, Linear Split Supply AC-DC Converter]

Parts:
C5, C6, C7, C8: 1000u 35V; CP_Radial_D10.0mm_P5.00mm
C9, C10: 22u 35V; CP_Radial_D5.0mm_P2.00mm
C11, C12: 100n; C_Disc_D5.0mm_W2.5mm_P5.00mm
D1, D3: LED; LED_D5.0mm_FlatTop
D2: W01G; Diode_Bridge_Round_D9.8mm
R5, R6: 10R; R_Axial_DIN0207_L6.3mm_D2.5mm_P10.16mm_Horizontal
R7, R8: 1k; R_Axial_DIN0207_L6.3mm_D2.5mm_P10.16mm_Horizontal
TP1: +15V; PinHeader_1x01_P2.54mm_Vertical
TP2: GND; PinHeader_1x01_P2.54mm_Vertical
TP3: -15V; PinHeader_1x01_P2.54mm_Vertical
U2: L7815; TO-220-3_Vertical
U3: L7915; TO-220-3_Vertical

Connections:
+15V: C9.1, C12.2, R7.2, TP1.1, U2.3 (OUT); also elsewhere on the board
-15V: C10.2, C11.1, R8.1, TP3.1, U3.3 (VO); also elsewhere on the board
/AC_1: D2.4; also elsewhere on the board
/AC_2: D2.2; also elsewhere on the board
GND: C5.2, C6.2, C7.1, C8.1, C9.2, C10.1, C11.2, C12.1, D1.1 (K), D3.2 (A), TP2.1, U2.2 (GND), U3.1 (GND); also elsewhere on the board
unnamed: D1.2 (A), R7.1
unnamed: C5.1, D2.1 (+), R6.1
unnamed: C7.2, D2.3 (-), R5.1
unnamed: D3.1 (K), R8.2
unnamed: C6.1, R6.2, U2.1 (IN)
unnamed: C8.2, R5.2, U3.2 (VI)


Board: 2 copper layers, 114.9 x 54.0 mm, 43 parts (0 on the bottom side), 21 nets.

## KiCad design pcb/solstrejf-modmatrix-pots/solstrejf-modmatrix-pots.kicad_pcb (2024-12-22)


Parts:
H1, H2, H3, H4: MountingHole; MountingHole_3.2mm_M3_DIN965
J1, J2, J3, J4: Conn_02x08_Counter_Clockwise; IDC-Header_2x08_P2.54mm_Vertical

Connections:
/V1AMP1: J1.15; also elsewhere on the board
/V1AMP2: J1.13; also elsewhere on the board
/V1AMP3: J1.12; also elsewhere on the board
/V1AMP4: J1.6; also elsewhere on the board
/V1FREQ1: J1.16; also elsewhere on the board
/V1FREQ2: J1.11; also elsewhere on the board
/V1FREQ3: J1.10; also elsewhere on the board
/V1FREQ4: J1.4; also elsewhere on the board
/V1PAN1: J1.14; also elsewhere on the board
/V1PAN2: J1.9; also elsewhere on the board
/V1PAN3: J1.8; also elsewhere on the board
/V1PAN4: J1.2; also elsewhere on the board
/V2AMP1: J2.15; also elsewhere on the board
/V2AMP2: J2.13; also elsewhere on the board
/V2AMP3: J2.12; also elsewhere on the board
/V2AMP4: J2.6; also elsewhere on the board
/V2FREQ1: J2.16; also elsewhere on the board
/V2FREQ2: J2.11; also elsewhere on the board
/V2FREQ3: J2.10; also elsewhere on the board
/V2FREQ4: J2.4; also elsewhere on the board
/V2PAN1: J2.14; also elsewhere on the board
/V2PAN2: J2.9; also elsewhere on the board
/V2PAN3: J2.8; also elsewhere on the board
/V2PAN4: J2.2; also elsewhere on the board
/V3AMP1: J3.15; also elsewhere on the board
/V3AMP2: J3.13; also elsewhere on the board
/V3AMP3: J3.12; also elsewhere on the board
/V3AMP4: J3.6; also elsewhere on the board
/V3FREQ1: J3.16; also elsewhere on the board
/V3FREQ2: J3.11; also elsewhere on the board
/V3FREQ3: J3.10; also elsewhere on the board
/V3FREQ4: J3.4; also elsewhere on the board
/V3PAN1: J3.14; also elsewhere on the board
/V3PAN2: J3.9; also elsewhere on the board
/V3PAN3: J3.8; also elsewhere on the board
/V3PAN4: J3.2; also elsewhere on the board
/V4AMP1: J4.15; also elsewhere on the board
/V4AMP2: J4.13; also elsewhere on the board
/V4AMP3: J4.12; also elsewhere on the board
/V4AMP4: J4.6; also elsewhere on the board
/V4FREQ1: J4.16; also elsewhere on the board
/V4FREQ2: J4.11; also elsewhere on the board
/V4FREQ3: J4.10; also elsewhere on the board
/V4FREQ4: J4.4; also elsewhere on the board
/V4PAN1: J4.14; also elsewhere on the board
/V4PAN2: J4.9; also elsewhere on the board
/V4PAN3: J4.8; also elsewhere on the board
/V4PAN4: J4.2; also elsewhere on the board
/VOICE1: J1.1, J1.3; also elsewhere on the board
/VOICE2: J2.1, J2.3; also elsewhere on the board
/VOICE3: J3.1, J3.3; also elsewhere on the board
/VOICE4: J4.1, J4.3; also elsewhere on the board
GND: J1.5, J1.7, J2.5, J2.7, J3.5, J3.7, J4.5, J4.7; also elsewhere on the board

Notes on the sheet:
M3 mounting holes for front panel assembly


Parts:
RV1, RV2, RV3, RV4, RV5, RV6, RV7, RV8, RV9, RV10, RV11, RV12: B10K; Potentiometer_Alpha_slide_pot_30mm

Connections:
/V1AMP1: RV1.2; also elsewhere on the board
/V1AMP2: RV4.2; also elsewhere on the board
/V1AMP3: RV7.2; also elsewhere on the board
/V1AMP4: RV10.2; also elsewhere on the board
/V1FREQ1: RV2.2; also elsewhere on the board
/V1FREQ2: RV5.2; also elsewhere on the board
/V1FREQ3: RV8.2; also elsewhere on the board
/V1FREQ4: RV11.2; also elsewhere on the board
/V1PAN1: RV3.2; also elsewhere on the board
/V1PAN2: RV6.2; also elsewhere on the board
/V1PAN3: RV9.2; also elsewhere on the board
/V1PAN4: RV12.2; also elsewhere on the board
/VOICE1: RV1.1, RV2.1, RV3.1; also elsewhere on the board
/VOICE2: RV4.1, RV5.1, RV6.1; also elsewhere on the board
/VOICE3: RV7.1, RV8.1, RV9.1; also elsewhere on the board
/VOICE4: RV10.1, RV11.1, RV12.1; also elsewhere on the board
GND: RV1.3, RV2.3, RV3.3, RV4.3, RV5.3, RV6.3, RV7.3, RV8.3, RV9.3, RV10.3, RV11.3, RV12.3; also elsewhere on the board

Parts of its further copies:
RV13, RV14, RV15, RV16, RV17, RV18, RV19, RV20, RV21, RV22, RV23, RV24, RV25, RV26, RV27, RV28, RV29, RV30, RV31, RV32, RV33, RV34, RV35, RV36, RV37, RV38, RV39, RV40, RV41, RV42, RV43, RV44, RV45, RV46, RV47, RV48: B10K; Potentiometer_Alpha_slide_pot_30mm

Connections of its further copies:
/V2AMP1: RV13.2; also elsewhere on the board
/V2AMP2: RV16.2; also elsewhere on the board
/V2AMP3: RV19.2; also elsewhere on the board
/V2AMP4: RV22.2; also elsewhere on the board
/V2FREQ1: RV14.2; also elsewhere on the board
/V2FREQ2: RV17.2; also elsewhere on the board
/V2FREQ3: RV20.2; also elsewhere on the board
/V2FREQ4: RV23.2; also elsewhere on the board
/V2PAN1: RV15.2; also elsewhere on the board
/V2PAN2: RV18.2; also elsewhere on the board
/V2PAN3: RV21.2; also elsewhere on the board
/V2PAN4: RV24.2; also elsewhere on the board
/V3AMP1: RV25.2; also elsewhere on the board
/V3AMP2: RV28.2; also elsewhere on the board
/V3AMP3: RV31.2; also elsewhere on the board
/V3AMP4: RV34.2; also elsewhere on the board
/V3FREQ1: RV26.2; also elsewhere on the board
/V3FREQ2: RV29.2; also elsewhere on the board
/V3FREQ3: RV32.2; also elsewhere on the board
/V3FREQ4: RV35.2; also elsewhere on the board
/V3PAN1: RV27.2; also elsewhere on the board
/V3PAN2: RV30.2; also elsewhere on the board
/V3PAN3: RV33.2; also elsewhere on the board
/V3PAN4: RV36.2; also elsewhere on the board
/V4AMP1: RV37.2; also elsewhere on the board
/V4AMP2: RV40.2; also elsewhere on the board
/V4AMP3: RV43.2; also elsewhere on the board
/V4AMP4: RV46.2; also elsewhere on the board
/V4FREQ1: RV38.2; also elsewhere on the board
/V4FREQ2: RV41.2; also elsewhere on the board
/V4FREQ3: RV44.2; also elsewhere on the board
/V4FREQ4: RV47.2; also elsewhere on the board
/V4PAN1: RV39.2; also elsewhere on the board
/V4PAN2: RV42.2; also elsewhere on the board
/V4PAN3: RV45.2; also elsewhere on the board
/V4PAN4: RV48.2; also elsewhere on the board
/VOICE1: RV13.1, RV14.1, RV15.1, RV25.1, RV26.1, RV27.1, RV37.1, RV38.1, RV39.1; also elsewhere on the board
/VOICE2: RV16.1, RV17.1, RV18.1, RV28.1, RV29.1, RV30.1, RV40.1, RV41.1, RV42.1; also elsewhere on the board
/VOICE3: RV19.1, RV20.1, RV21.1, RV31.1, RV32.1, RV33.1, RV43.1, RV44.1, RV45.1; also elsewhere on the board
/VOICE4: RV22.1, RV23.1, RV24.1, RV34.1, RV35.1, RV36.1, RV46.1, RV47.1, RV48.1; also elsewhere on the board
GND: RV13.3, RV14.3, RV15.3, RV16.3, RV17.3, RV18.3, RV19.3, RV20.3, RV21.3, RV22.3, RV23.3, RV24.3, RV25.3, RV26.3, RV27.3, RV28.3, RV29.3, RV30.3, RV31.3, RV32.3, RV33.3, RV34.3, RV35.3, RV36.3, RV37.3, RV38.3, RV39.3, RV40.3, RV41.3, RV42.3, RV43.3, RV44.3, RV45.3, RV46.3, RV47.3, RV48.3; also elsewhere on the board

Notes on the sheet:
Pan Modulation
Amplitude Modulation
Frequency Modulation



Board: 2 copper layers, 165.1 x 246.9 mm, 56 parts (4 on the bottom side), 53 nets.

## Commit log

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2024-05-23 created the PSU and L/R audio mixer KiCad project. Schematic Done. PCB footprints importet
    [audio_mixer.kicad_sch, power_supply.kicad_sch, solstrejf-PSU-mixer.kicad_pcb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]
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2024-06-13 updated KiCad schematic and PCB with the new changes added to the TIA after LTspice simulations.
    [audio_mixer.kicad_sch, power_supply.kicad_sch, solstrejf-PSU-mixer.kicad_pcb]
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2024-07-12 made first attempt of a PCB layout onf the PSU/mixer. No routing performed. Minor updates to schematic, including mounting holes.
    [audio_mixer.kicad_sch, power_supply.kicad_sch, solstrejf-PSU-mixer.kicad_pcb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]
2024-07-15 routing of PSU/mixer done! Minor schematic updates. Added gerber production files to .gitignore.
    [power_supply.kicad_sch, solstrejf-PSU-mixer.kicad_pcb, solstrejf-PSU-mixer.kicad_sch]
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2024-08-21 Added kromftronics custom kicad files as submodule. Updated modmatrix KiCad project to use the submodule.
    [modmatrix-single-column.kicad_sch, solstrejf-modmatrix-pots.kicad_pcb]
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2024-08-24 Updated fonts in PSU+mixer schematic. Added a print of the PSU+mixer schemtic in new directory.
    [audio_mixer.kicad_sch, power_supply.kicad_sch, solstrejf-PSU-mixer.kicad_sch]
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2024-08-24 Created hierarchical pins for the three CV sub-circuits and added the rest of the core circuitry for the voice board.
    [frequency_cv.kicad_sch, pan_cv.kicad_sch, solstrejf-voiceboard-core.kicad_sch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]
2024-08-25 Updated LTspice simulation of output TIA with decrease volume pot for 15.92Hz highpass frequency. Updated KiCad and images with the same change.
    [audio_mixer.kicad_sch, solstrejf-PSU-mixer.kicad_pcb]
2024-08-27 created schematic for CV circuits: PAN, VCA, and FREQ. Created a new symbol for the ONESHOT envelope generator
    [frequency_cv.kicad_sch, pan_cv.kicad_sch, solstrejf-voiceboard-core.kicad_sch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]
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2024-08-31 created voice board front panel KiCad projects. Made some updates in the Kromftronics KiCad repo.
    [solstrejf-voiceboard-frontpanel.kicad_pcb, solstrejf-voiceboard-frontpanel.kicad_sch, vca_cv.kicad_sch]
2024-09-01 updated Kromftronics submodule name and edited path in all PCB projects. Added work-in-progress for the front-panel PCB and the small updates in the voice-board schematic
    [solstrejf-voiceboard-core.kicad_sch, solstrejf-voiceboard-frontpanel.kicad_pcb, solstrejf-voiceboard-frontpanel.kicad_sch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]
2024-09-01 Updated modmatrix project: added more silkscreen and removed rounded edges. Stored 3D models in mod-matrix project for better portability. Added new images of the current state of the mod-matrix PCB.
    [solstrejf-modmatrix-pots.kicad_pcb]
2024-09-01 Updated voice board front-panel and mod-matrix
    Created new dimensions to get a better physical layout of the 4x voice board control panels and the mod-matrix.
    Exported .wrl 3D models of voice board front-panel and mod-matrix to create a MeshLab view.
    Added MeshLab project files and new images aswell.
    [solstrejf-modmatrix-pots.kicad_pcb, solstrejf-modmatrix-pots.kicad_sch, solstrejf-voiceboard-frontpanel.kicad_pcb]
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2024-09-02 Updated frequency CV summer circuit to use +/-12V local regulator instead of +/15V. Updated LTspice, notebooks, and KiCad project
    [frequency_cv.kicad_sch, pan_cv.kicad_sch, solstrejf-voiceboard-core.kicad_sch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]
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2024-09-07 Updated mod-matrix PCB to have a hole for master volume pot
    Added a M8 hole in the mod-matrix PCB to be able to attach the stereo master volume control.
    Updated the images of the mod-matrix and the meshlab render.
    [solstrejf-modmatrix-pots.kicad_pcb]
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2024-10-28 Found an error in the front panel where the volume pot was inverted. Updated the schematics of the voice board core and front panel.
    [frequency_cv.kicad_sch, pan_cv.kicad_sch, solstrejf-voiceboard-core.kicad_pcb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]
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2024-11-02 Updated potentiometer value from B10k to B10K in order for all of the slide pots to have the same value in the BOM. Generated ibom for the mod-matrix board.
    [modmatrix-single-column.kicad_sch, solstrejf-modmatrix-pots.kicad_pcb]
2024-11-02 Updated values of electrolytic caps on voice board to match in the ibom.
    [frequency_cv.kicad_sch, solstrejf-voiceboard-core.kicad_pcb, voiceboard_power.kicad_sch]
2024-11-18 Fixed a footprint error in the Alpha slide pot. Pad holes were 0.7mm in diameter, but needed to be 1mm. Updated this in mod-matrix and front panel control.
    [solstrejf-modmatrix-pots.kicad_pcb, solstrejf-voiceboard-frontpanel.kicad_pcb]
2024-11-18 Created rev1.1 for mod-matrix and voice board front panel. Exported a new ibom for both of them.
    [solstrejf-modmatrix-pots.kicad_pcb, solstrejf-voiceboard-frontpanel.kicad_pcb]
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2024-11-25 updated Alpha slide pot footprint to have 1.2mm drill hole diameter to match the 1mm pins
    [solstrejf-modmatrix-pots.kicad_pcb, solstrejf-voiceboard-frontpanel.kicad_pcb]
2024-11-25 Added the correct version of the KiCad footprint library with the modified Alpha slide pot footprint
2024-12-22 Added variable revision and date silkscreen prints for all four boards of Solstrejf
    This means that the revision and issue date that is set in the page setup
    of the PCB's will be update on the silscreen automatically so I don't forget
    to update the revsions on the silkscreen :')
    [solstrejf-PSU-mixer.kicad_pcb, solstrejf-modmatrix-pots.kicad_pcb, solstrejf-voiceboard-core.kicad_pcb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]
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2025-03-01 Created rev1.1 of Solstref voice board. Updated value of some resistors (66k->68k). Exported new ibom and schematic.
    [frequency_cv.kicad_sch, pan_cv.kicad_sch, solstrejf-voiceboard-core.kicad_pcb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]
2025-03-02 Updated resistor value in VCF CV circuit. Generated new ibom and schematic.
    [frequency_cv.kicad_sch, pan_cv.kicad_sch, solstrejf-voiceboard-core.kicad_pcb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]
2025-03-08 Updated two capacitor values in voice board power section 330n->100n. Updated Schematic and created new IBOM.
    [frequency_cv.kicad_sch, pan_cv.kicad_sch, solstrejf-voiceboard-core.kicad_pcb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]
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2026-01-29 updated frontpanel trig opamp output resistor due
    - the weak pull-up on the ONESHOT env cause errors with creating zeros
    [solstrejf-voiceboard-frontpanel.kicad_pcb, solstrejf-voiceboard-frontpanel.kicad_sch]
